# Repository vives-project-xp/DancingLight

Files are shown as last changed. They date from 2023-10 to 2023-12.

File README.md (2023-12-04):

# Dancing Light

## Content

- [Project explained](#project-explained)
- [Effects](#effects)
- [Hardware](#hardware)
- [Software](#software) 
- [Who does/did what?](#who-doesdid-what)
- [Planning](#planning)
- [Future changes](#future-changes)
- [BOM](#bom)
- [Links](#links)
- [License and author info](#license-and-author-info)

## Project explained

The Dancing Light project will make LED's react to music.

We will be working with a sound sensor which will send a signal depending on the strength of the sound/music. Using a Raspberry Pi 4 we can code a program to make this happen. We used VNC for most of our programming (more info in software).

The project will have a few modes. Some generic effects will be added into a program. Lastly the mode which listens to audio input will also be implemented into the project. We use a USB mic to listen to the audio due to the Raspberry Pi only being able to take in digital input on the GPIO pins.

With this mic we can connect it to a USB port on the Pi and make a program which can observe analog input. This way we can visualize sound strength, frequencies and other sound related variables. With the digital pin reading (old mic) way we can only display light for the on and off state.

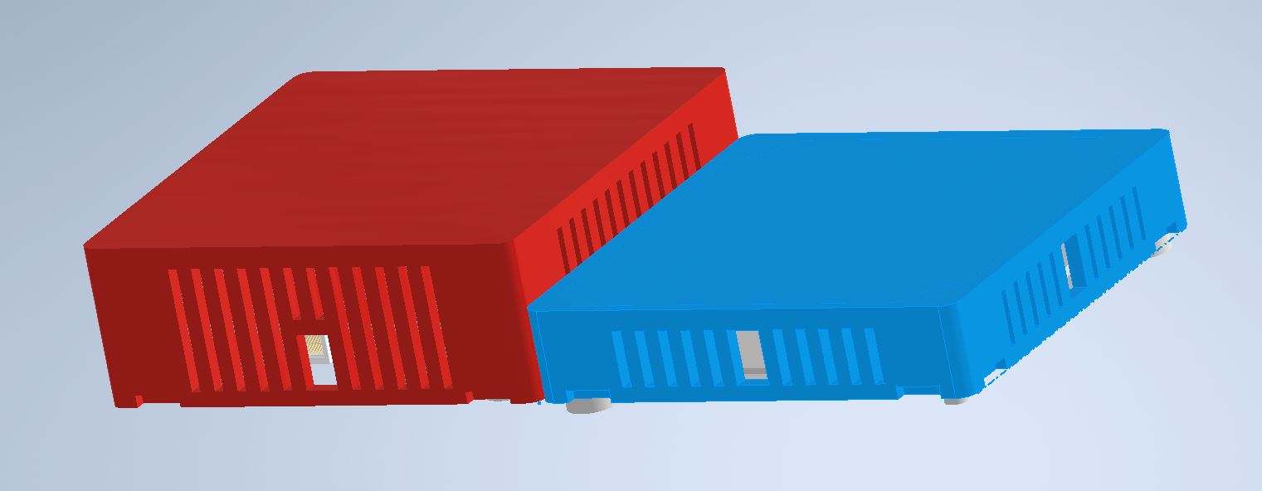
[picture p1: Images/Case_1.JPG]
Case

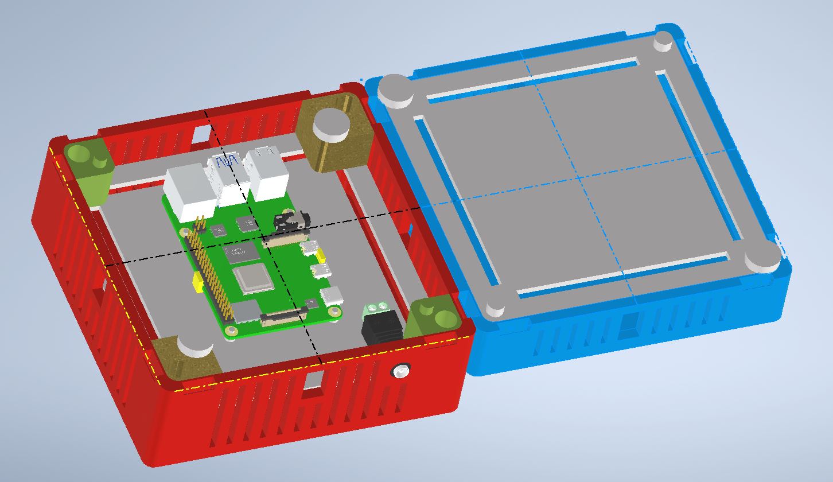
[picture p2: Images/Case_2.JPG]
Case


Taking the entire casing into account it exists out of four different parts. The lid has some holes for air circulation and the top is printed very thin, just so the light of the LEDs is visible from the outside.

At the sides a system was added to connect two cases with each other. It uses an external part to connect the sides. To ensure the same lighting in each box, we decided to add the Pi to the back of the main box. This will make it so the main box will be coming forward when compared to the other boxes when connected to for example a wall. For this proof of concept project we will make three boxes (one with raspberry and two without).

Originally we used two parts which would bridge over the Pi to provide light all over the box, but this caused the issue that you could visually see the LED's on one side and only the light on the other side.

## Effects
These are the effects supported with the MQTT broker
<ul>
    <li>"MiddenBounce"</li>
    <li>"uitbreidReactie"</li>
    <li>"vlakMuziek"</li>
    <li>"ledsMeDb"</li>
    <li>"ledsMeDbFlikker"</li>
    <li>"rainbow"</li>
    <li>"rgbKleur" (rgb effect)</li>
    <li>"ledsMeDbRGB" (rgb effect)</li>
</ul>

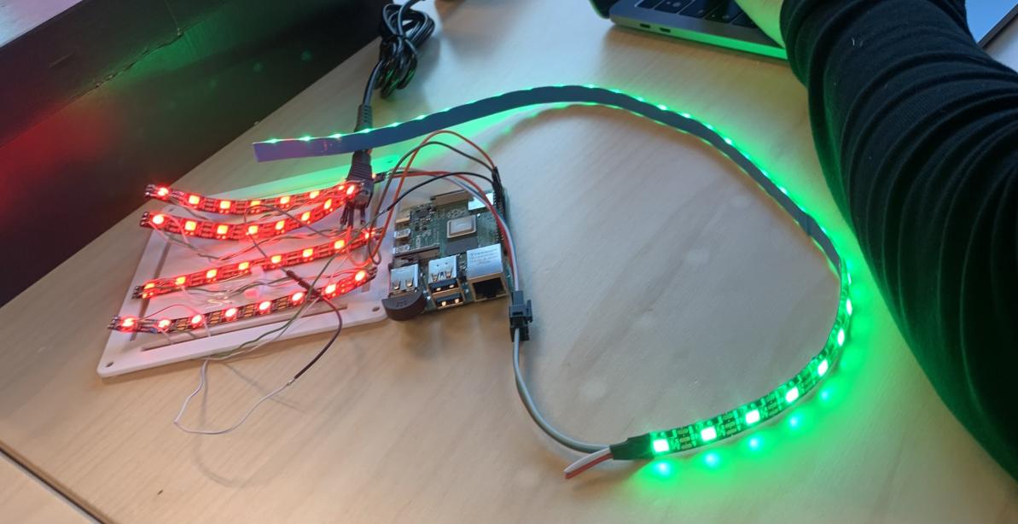
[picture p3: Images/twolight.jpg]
2lights


## Hardware

Our project requires the following hardware and materials to be constructed (links and pricing included in BOM list):

### 1. Raspberry Pi 4

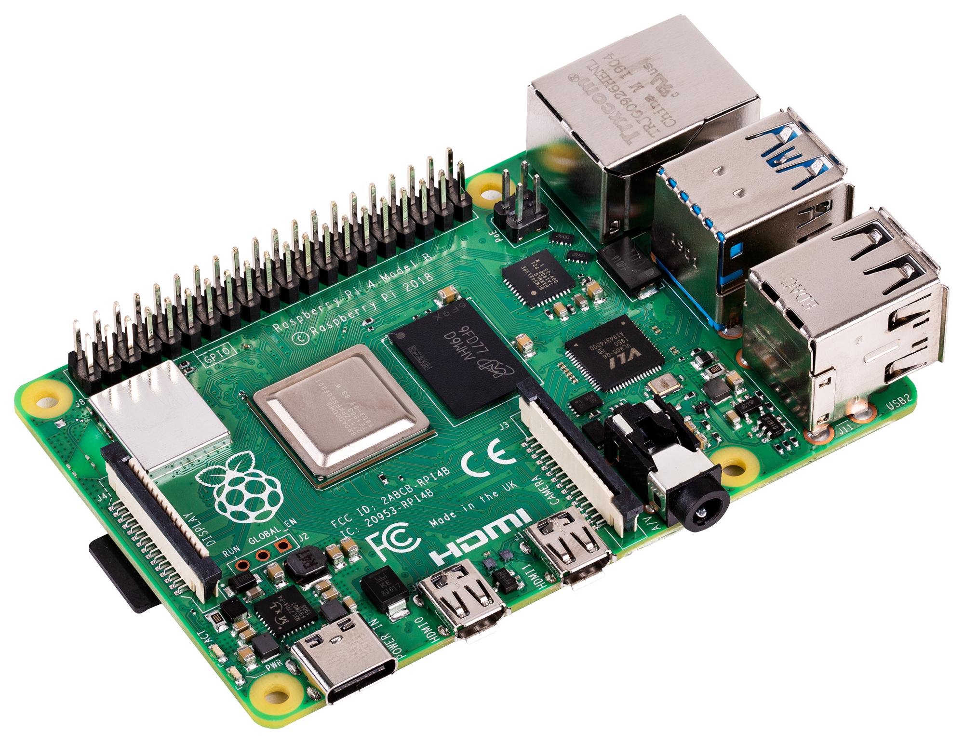
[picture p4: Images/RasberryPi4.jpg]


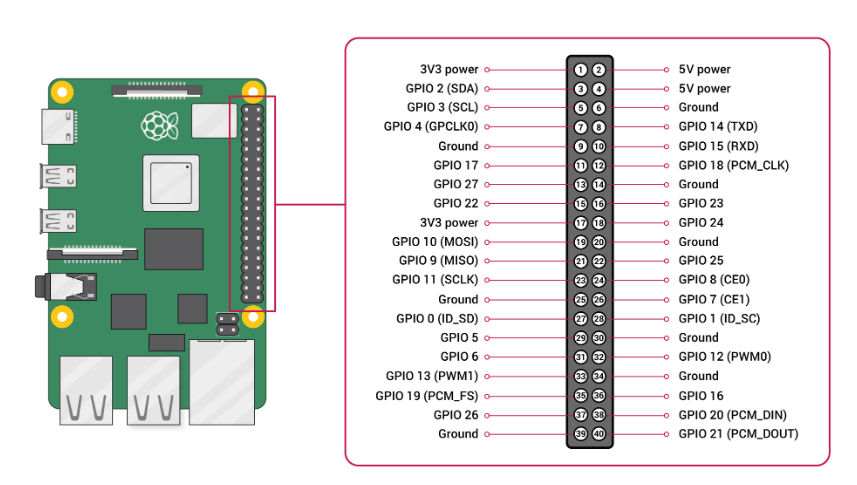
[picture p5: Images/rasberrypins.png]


We use a Raspberry Pi 4 to power and drive our project, this is a powerful way in which we can include many different effects.

### 2. Plug adapter 5V 10A

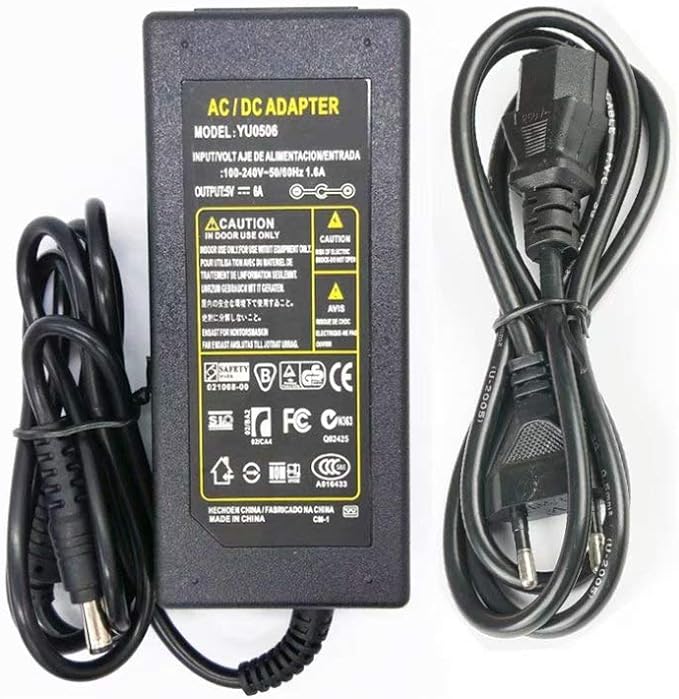
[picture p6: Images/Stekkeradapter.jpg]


Of course the Raspberry Pi 4 needs power to work, for that we use this adapter.

### 3. Adapter -> DC

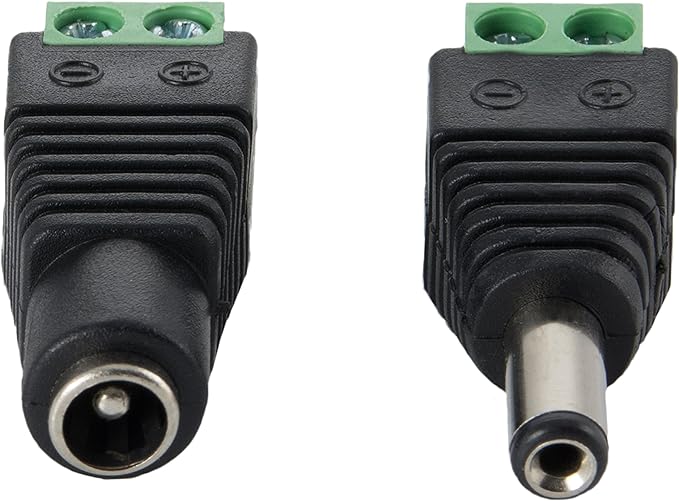
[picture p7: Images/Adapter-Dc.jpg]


### 4. 3 Pin Connector

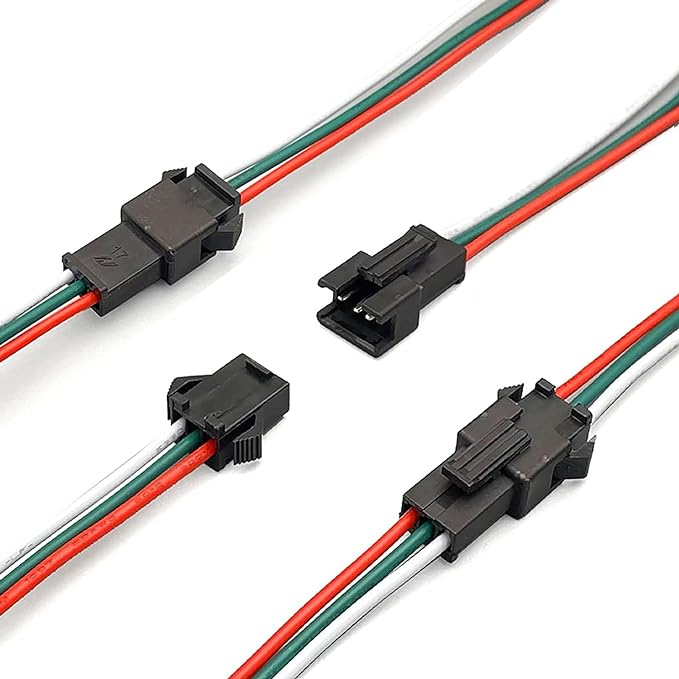
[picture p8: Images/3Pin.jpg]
3Pin


To connect LED strips we use these connectors, which can easily connect LED strips to eachother by just plugging one end into another. 

### 5. LED strip 5V

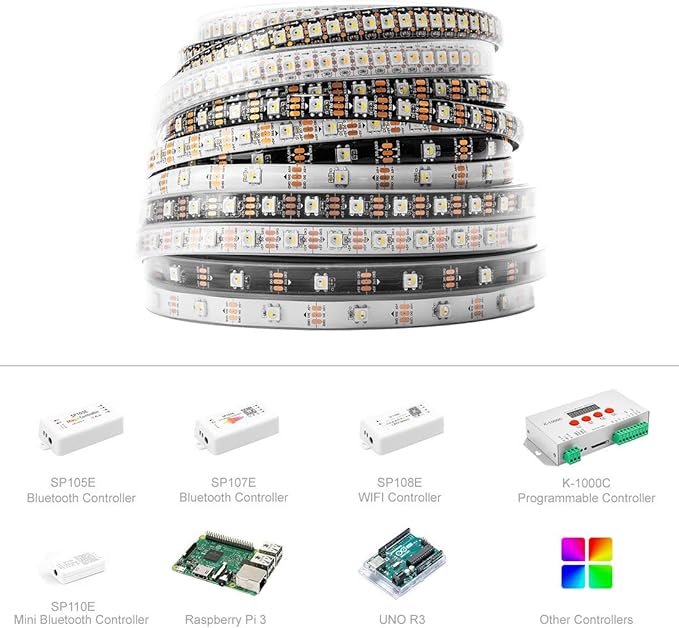
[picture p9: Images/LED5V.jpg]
LEDS


### 6. Sound sensor

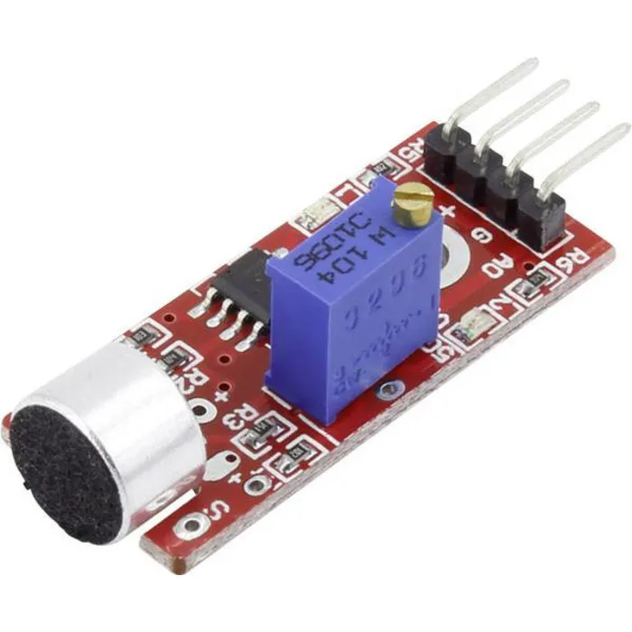
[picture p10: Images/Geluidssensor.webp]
Geluidssensor


Dropped due to low sensitivity, could also only be connected to digital GPIO pins. This way we had to work with a specific value to work around and can also only play an effect when this value is exceeded.

### 7. USB microphone

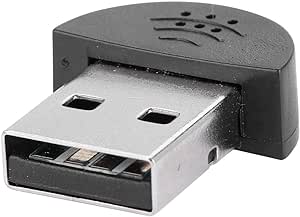
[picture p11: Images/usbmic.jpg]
usb


We chose to use a different approach by using this USB-mic to be able to take in analog input to create effects based on the strength of the sound. With some calculations found online we can determine the decibel rate of the sound. This mic is way more sensitive to sound, even lighting up from silent sounds far away (depending on the chosen value of course).

### 8. Casing 3D prints

## Software

### 1. [VNC Viewer](https://www.realvnc.com/en/connect/download/viewer/):

This is the software we used to program the Raspberry Pi 4. It's easy to set up after installing. An advantage of this software is the ability to work on the same project at the same time. Whenever one person changes something all other members see the changes on their own device live.

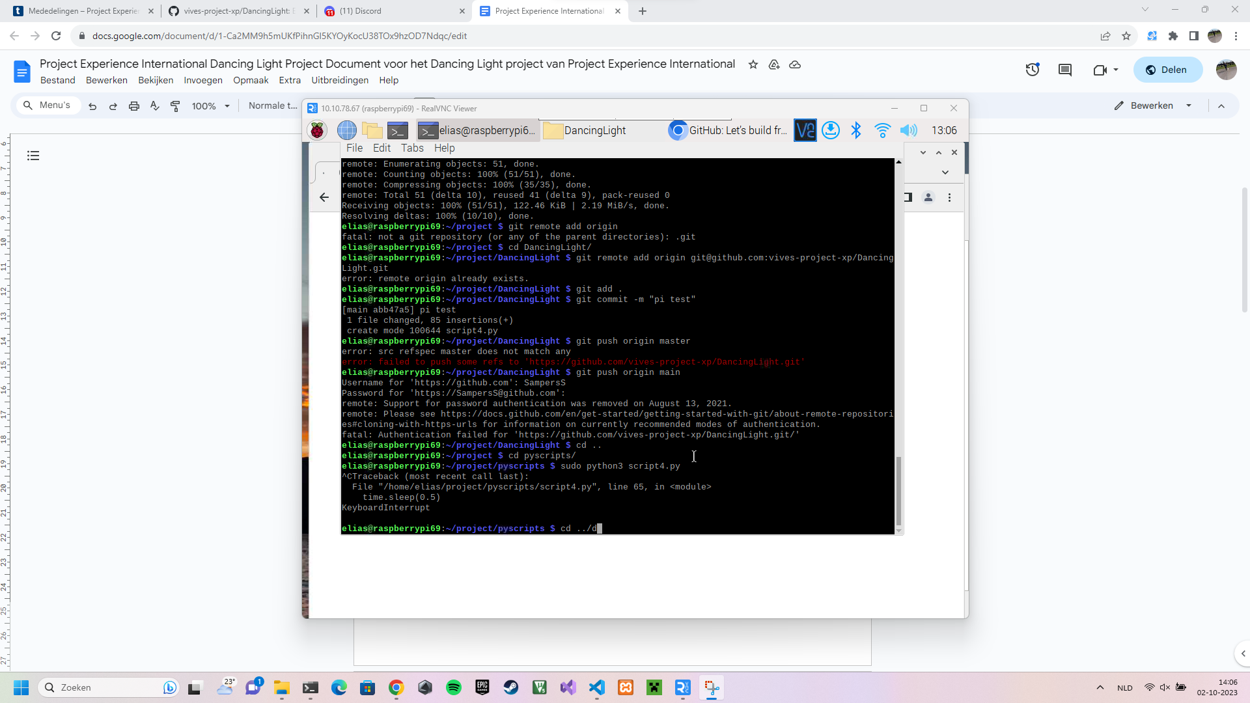
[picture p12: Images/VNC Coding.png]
vnc


&nbsp;

### 2. Python coding environment

VNC viewer has the ability to write code in the program itself, opening the right type of file in your folder.

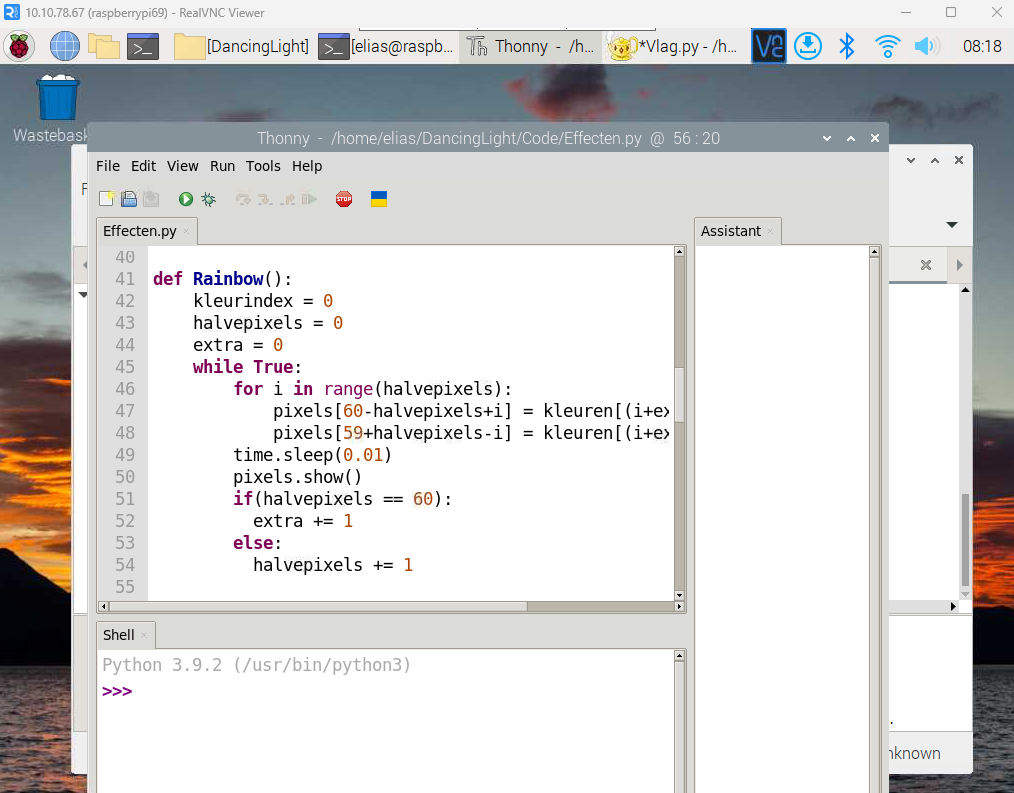
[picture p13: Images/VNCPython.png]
vncpy


### 3. MQTT with [Project Master](https://github.com/vives-project-xp/ProjectMaster)

MQTT gives us the ability to connect with the Project Master. Which makes it possible to send the effects from a central device to the different projects.

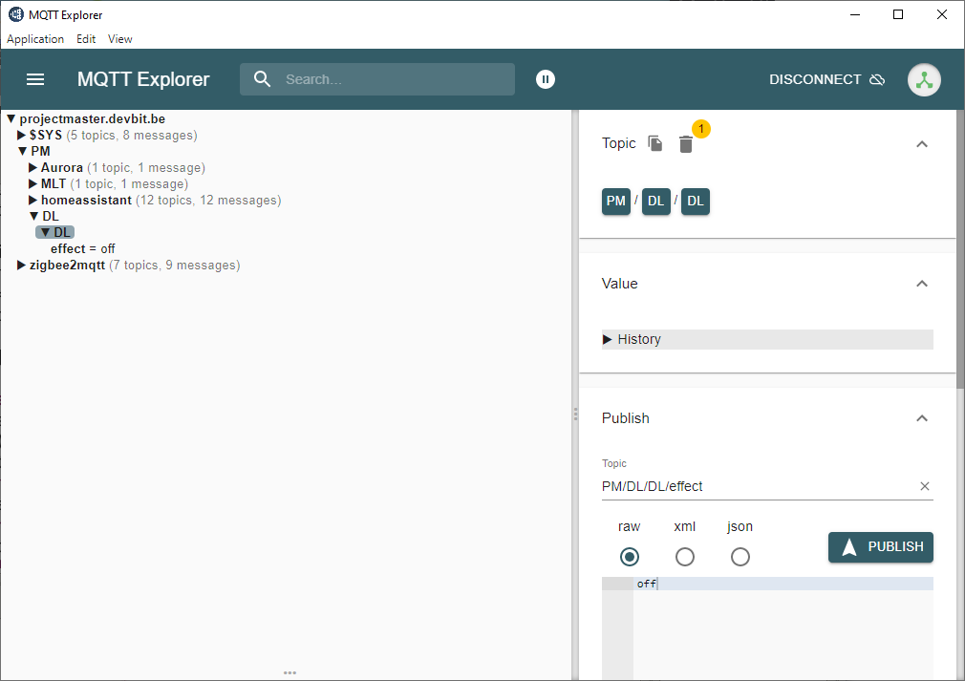
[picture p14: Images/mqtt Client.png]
mqtt


### 4. [Autodesk Inventor Professional 2021](https://www.autodesk.com/products/inventor/overview?term=1-YEAR&tab=subscription)

Inventor gives the ability to make 3D designs for making this project possible. This program also makes it easy to convert the 3D designs to STL files for 3D printing.

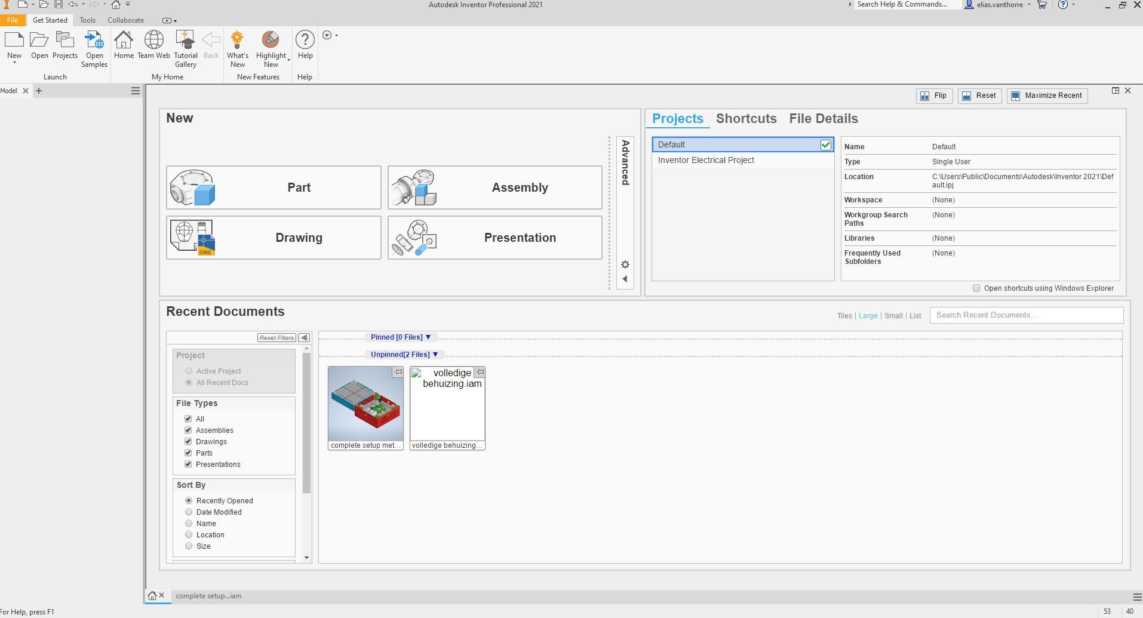
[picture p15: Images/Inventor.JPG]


## How is the box build?
WARNING: When picking the project up from the amgnet board you need to be carefull to not pull it off to quick. And brake the project also the boxes are connect with clips so be carefull when pulling the different boxes apart. 

To disasemble the setup you first need to pull the boxes apart and pull out the clips inbetween of the two boxes.
Secondly you screw off the magnets who are inserted in to the standoffs on both boxes. When the magnets are of you will be able to pull of the lid from the smaller box and you will see the leds. For the bigger boxs you will need to first screw off the spacers out of the biggerbox. These screws are pretty thight so be carefull when unscrewing them. When alle the spacer are unscrewed you will be able to pull of the lid from the bigger box with the pi and wires still attage. For the ease of use you can disconnect the wires going to the pi to get a look in the bigger box. Everything is power by the famel plug and this one is glued in place so be carefull when pulling out the lid. 

## Who does/did what?

- ### Global (entire group)

1. Project defining (What's expected from the project)
2. Project design (Brainstorming about options, designing connection system for multiple products)
3. Material list (Searching cheapest solutions while maintaining quality)
4. Github issues
5. Group meetings

- ### Mirko (Software & ai + Scrum master)

1. Software testing (Making a LED strip function like we want with the Raspberry Pi 4)
2. Searching code
3. Issue management
4. MQTT
5. Coding effects

- ### Seraphin (Software & ai)

1. Software testing (Making a LED strip function like we want with the Raspberry Pi 4)
2. Searching code
3. Rasberry configuration
4. MQTT
5. Coding effects
6. Sound detection on raspberry pi 4

- ### William (Software & ai)

1. Poster design
2. Presentation
3. Searching code for the microphones
4. Integrating hardware to the Raspberry Pi.

- ### Elias (Networks)

1. Looking for power supply solution
2. Case design
3. Rasberry configuration
4. Soldering
5. Assembly
6. README documentation
7. README 3D

- ### Esteban (Software & ai)

1. README documentation
2. Searching code
3. Coding to read mp3 file (and sound visualisation script)
4. Sound coding
5. Coding effects

- ### Planning

1. Testing product (week 7-10)/
    - Software and hardware
    - Casing (does the connection between two products work?)
        1. Top of first case was printed to thick (no light could pass)
        2. Do we use plastic or do we 3D print see trough layer.
2. Optimizing product:
    - Thinner top layer
    - Raspberry Pi added to the back of the case
3. Coding:
    - LED's on sound strength
    - Template lighting for LED's (Done)
4. Case connection (important)
5. MQTT connection (Project master)
6. Document finalization:
    - README
    - Powerpoint final presentation
    - Manage files on Pi
7. Preparing final presentation

## Future changes

1. Adding better solution for connecting the different boxes.
2. More effects

## BOM

| Description | Quantity | Price |
|---|---|---|
| Geluidssensor | 1 | [€0.99](https://www.otronic.nl/nl/geluidssensor-module-voor-arduino.html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) |
|SK6812 5V LED | 2m | [€23](https://www.amazon.nl/BTF-LIGHTING-Vergelijkbare-Individueel-Adresseerbare-Niet-Waterdicht/dp/B01N2PC9KK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) |
| Stekkeradapter 5V 10A 50W| 1 | [€21.99](https://www.amazon.nl/Transformatoren-AC100-240V-Omvormer-Stekkeradapter-Verlichting/dp/B07PBNCFDG?th=1) |
| Adapter omvormer | 1 | [€9.02](https://www.amazon.nl/Poppstar-Adapter-5x2-Connectors-CCTV-camera/dp/B084RHH8LC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) |
| 3Pin Connector | 1 | [€9.99](https://www.amazon.nl/HUAZIZ-vrouwelijk-mannelijke-vrouwelijke-elektrische/dp/B0BPP87N9G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) |
|Raspberry Pi |1|[€86.17](https://www.amazon.nl/Raspberry-Pi-ARM-Cortex-A72-Bluetooth-Micro-HDMI/dp/B07TC2BK1X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)|
|USB Microfoon|1|[€7.11](https://www.amazon.nl/Audio-opnemen-USB-microfoon-omnidirectioneel-Skype-chatten/dp/B08BFHSLGV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)|
| 3D printing | 1 | €4 (reserved) |

Total: €158.27 (3D printing excluded)

## Links

Github: https://github.com/vives-project-xp/DancingLight
Installatie instructies: https://github.com/vives-project-xp/DancingLight/blob/main/INSTALLATION.md

## License and author info

Made by Mirko Sinnaeve, Seraphin Sampers, William Rogov, Elias Vanthorre en Esteban Desmedt in 2023-2024, semester 1 for VIVES.

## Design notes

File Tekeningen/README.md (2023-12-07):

# 3D models

All parts are made in the software Inventor Professional 2021. To open the project the best thing to do is to open the assembly, "complete setup met relief", in the "13_11_2023" folder.

This way you open all the parts that are needed for this project and you can see how all the parts fit together. In the pictures below you will see the assembly with a numbering of what the parts are/what they do with the naming of this part. All the parts are 3D printed except the stand-offs and bought parts like the Raspberry Pi and barrel jack.

The folder with name "13_11_2023" is where all the latest pieces are. The other folder with name "13_11_2023 stukken niet meer nodig", are pieces who where made in the prototyping stage and are not needed anymore for the project.

If you want to remake this project on your own 3D printer that is possible with the 3D stl files provided in the map "STL 14-11-2023" and "STL 27-11-2023".

## Description of the parts

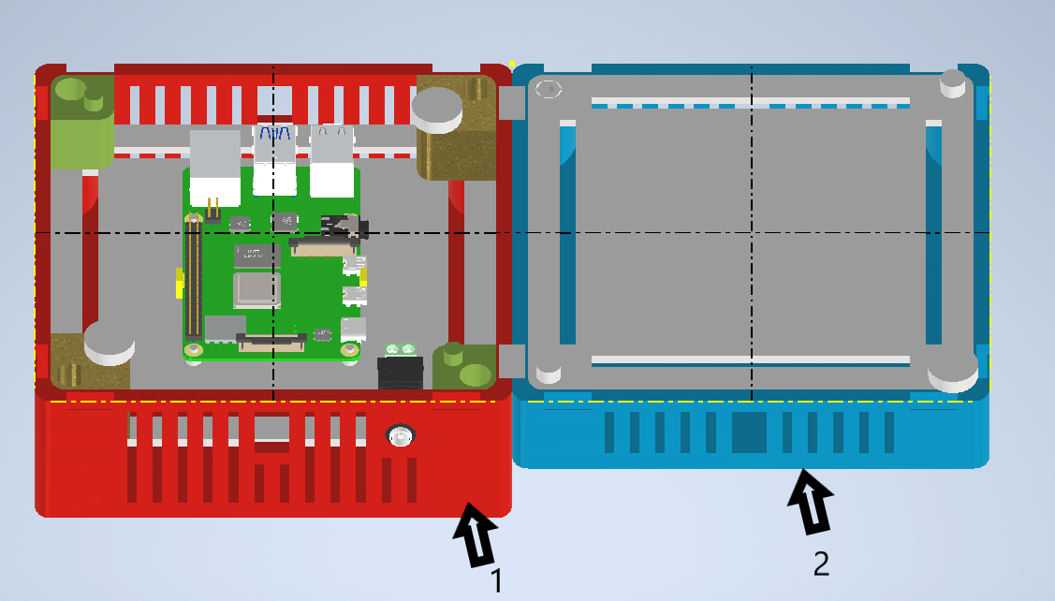
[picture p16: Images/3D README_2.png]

The name of each part in the 13_11_2023 folder is in brackets.

1. The highest case (Led behuizing dubbele hoogte).

2. The lower form of the case (Led behuizing).

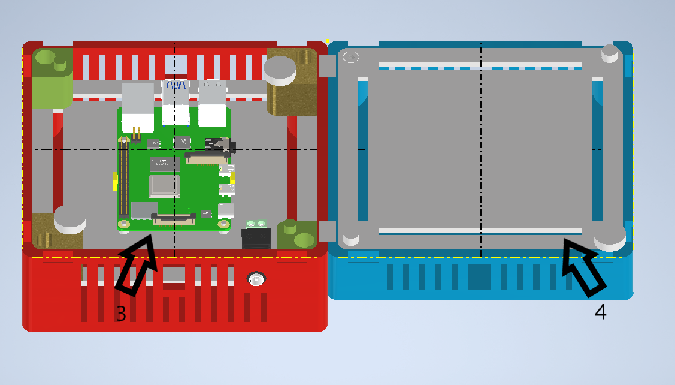
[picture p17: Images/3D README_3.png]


3. The lid where the Pi is mounted on (Led deksel hub).

4. The lid without a Pi (Led deksel hub zonder pi).

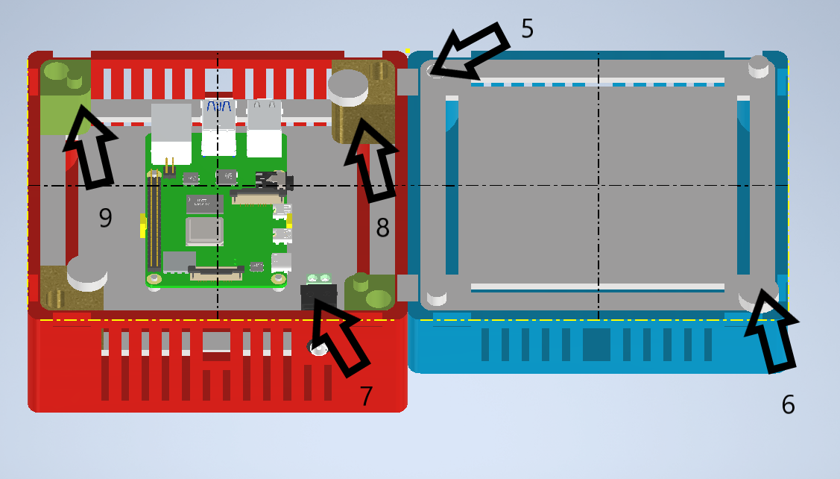
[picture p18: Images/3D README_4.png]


5. Magnet stand-offs small box (magneet stand-offs).

6. Magnet (magneet).

7. This is the power barrel jack this is an assembly in an assembly (dc-barrel-jack-adapter-female).

8. Spacer to make it possible to use the magnets (spacer dubbele hoogte behuizing).

9. Spacer without the magnets for the big box (spacer dubbele hoogte behuizing zonder magneet).

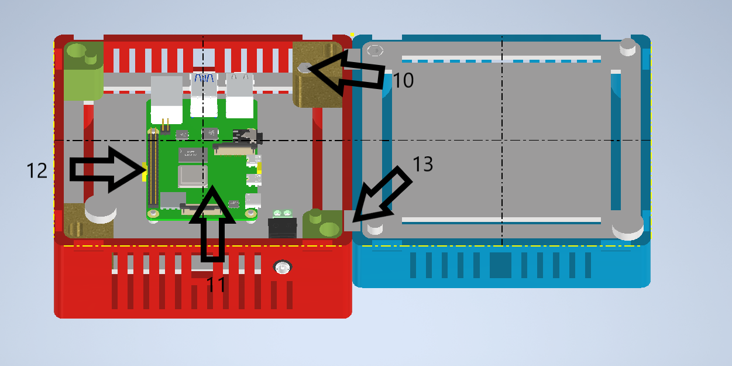
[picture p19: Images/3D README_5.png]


10. This is the spacer for the higher box (mangeet stand-offs16 mm).

11. This is the raspberry pi (Raspberry Pi 4 Model B).

12. The Pi holder that is glued on the lid (houderpi).

13. This is the merge piece that keeps the two boxes together (koppelstuk).

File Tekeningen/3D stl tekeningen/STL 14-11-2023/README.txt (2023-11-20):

Zowel de stl als de .gcode files heb ik hier geplaats. 
De .gcode files heb ik zelf gesliced via de crealty print slicer op basis van de ender-3 S1 PLUS. Maar met dezelfde settings waarmij ik op mijn eigen ender 3 pro de behuizing reeds geprint heb (succesvol).
Het gebruiken van deze .gcode is geen garantie op succes op de S1 PLUS maar het werd gevraagd dat ik deze reeds slice via mijn settigns vandaar.
De vorige print die ontvangen werd via het school had enige defecten zoals het warpen van de grote onderdelen als ook het niet mooi afwerken van openvlaktes. 
Wat me ook opviel bij de prints is dat deze op elk aspect toch enkele mms te groot uitvielen heb geen idee wat hiervan de reden zou kunnen zijn. (bij het printen thuis had ik hiermee niet direct een probleem)
in de images case_1 en case_2 krijg je een overzicht van hoe het geheel er zou moeten uitzien.

Naam stl						kleur			printer			aantal		opmerking

Houderpi 						gelijk 			gelijk			1		bij het gebruiken van de stl gelieve te zorgen dat de ribbel loodrecht light t.o.v. de build plate

Led behuizing dubbele hoogte				Wit			ender-3 S1 PLUS		1

Led behuizing						Wit			ender-3 S1 PLUS		1

Led deksel hub zonder pi				wit			ender-3 S1 PLUS		1

Led deksel hub						wit			ender-3 S1 PLUS		1

spacer dubbele hoogte behuizing zonder magneet		gelijk			gelijk			2

spacer dubbele hoogte behuizing				gelijk			gelijk			2

Als de keuze wordt gemaakt om mijn .gcode te gebruiken hier wat nuttige info (het kan zijn dat er wat stringing aanwezig is)

Naam .gcode								print tijd		support		infill

Ender-3 S1 Plus_Houderpi						15min			geen		50%
			
Ender-3 S1 Plus_Led behuizing dubbele hoogte				36h			ja		50%

Ender-3 S1 Plus_Led behuizing						22h			ja		50%

Ender-3 S1 Plus_Led deksel hub zonder pi				6h			geen 		50%

Ender-3 S1 Plus_Led deksel hub						6,15h			geen		50%

Ender-3 S1 Plus_spacer dubbele hoogte behuizing zonder magneet		1,1h			geen		50%

Ender-3 S1 Plus_spacer dubbele hoogte behuizing				1,3h			geen		50%

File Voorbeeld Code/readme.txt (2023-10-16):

in deze map zit code van het internet die de nodige stappen en ideën bevat om dingen te doen. Het is niet de bedoeling dat je deze code aanpast, je gebruikt dit enkel voor het copiëeren naar je eigen code. peace.

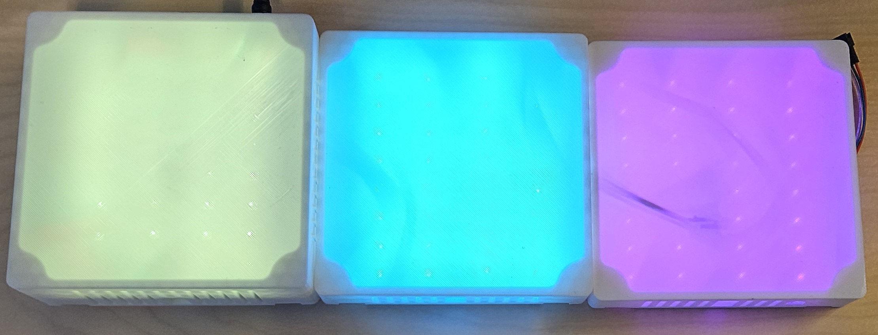
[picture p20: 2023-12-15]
Images/Presentatie/foto_2.jpg

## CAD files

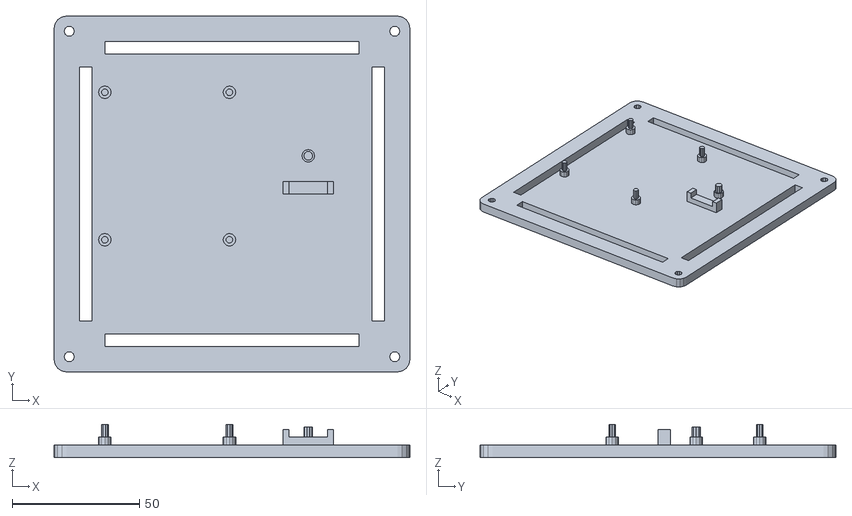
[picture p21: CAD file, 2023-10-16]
Tekeningen/3D stl tekeningen/STL 16-10-2023 niet meer nodig/Led deksel main unit.stl
140.0 x 140.0 x 13.0

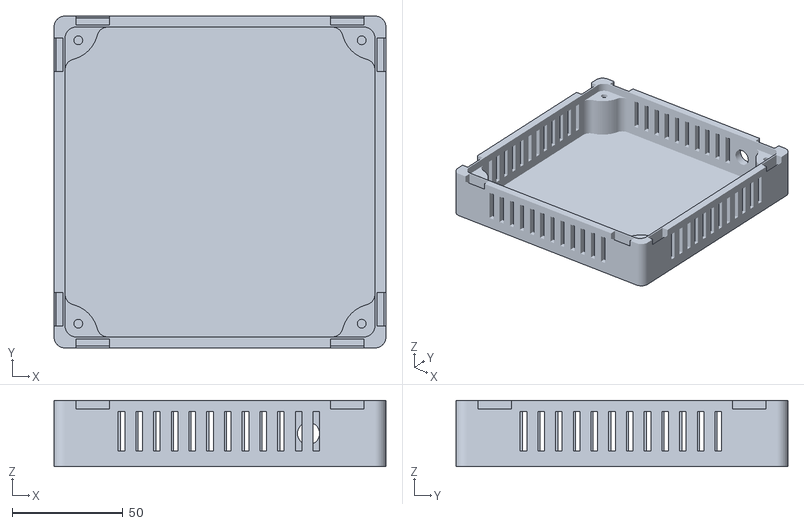
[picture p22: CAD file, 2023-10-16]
Tekeningen/3D stl tekeningen/STL 16-10-2023 niet meer nodig/Led behuizing main unit.stl
150.0 x 150.0 x 30.0

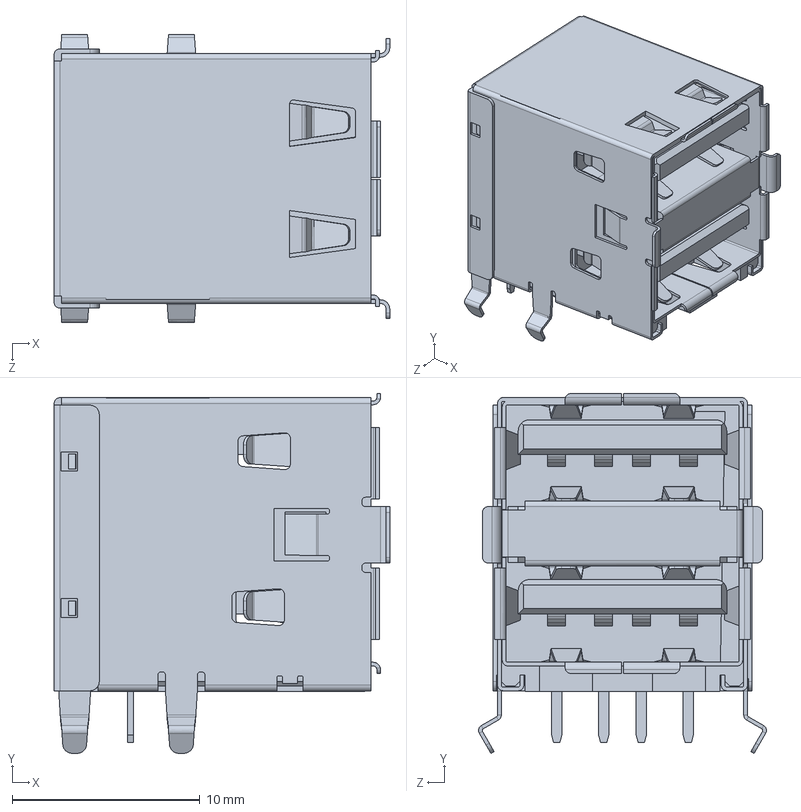
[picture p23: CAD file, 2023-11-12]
Tekeningen/13_11_2023 stukken niet meer nodig/raspberrypi/2X USB2.0 PORTS, RPi4ModelB.SLDPRT
17.9 x 19.2 x 15.3 mm

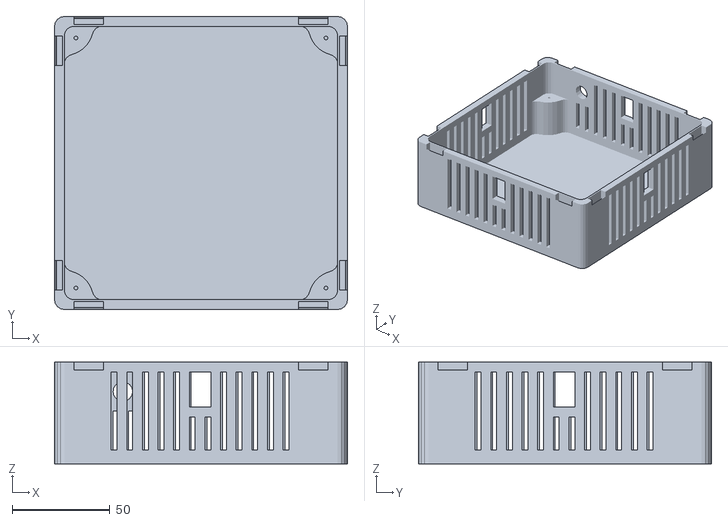
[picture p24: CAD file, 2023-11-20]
Tekeningen/3D stl tekeningen/STL 14-11-2023/Led behuizing dubbele hoogte.stl
150.0 x 150.0 x 52.0

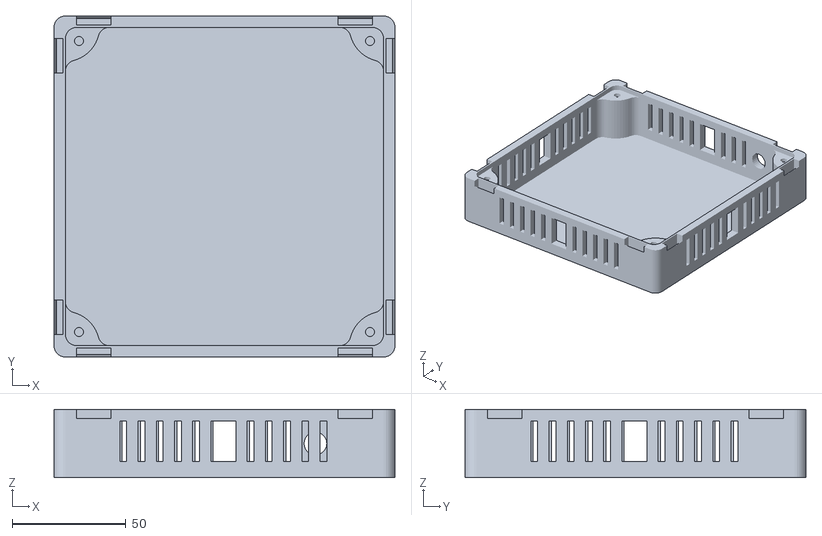
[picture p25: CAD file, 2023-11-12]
Tekeningen/3D stl tekeningen/STL 16-10-2023 niet meer nodig/Led behuizing.stl
150.0 x 150.0 x 30.0

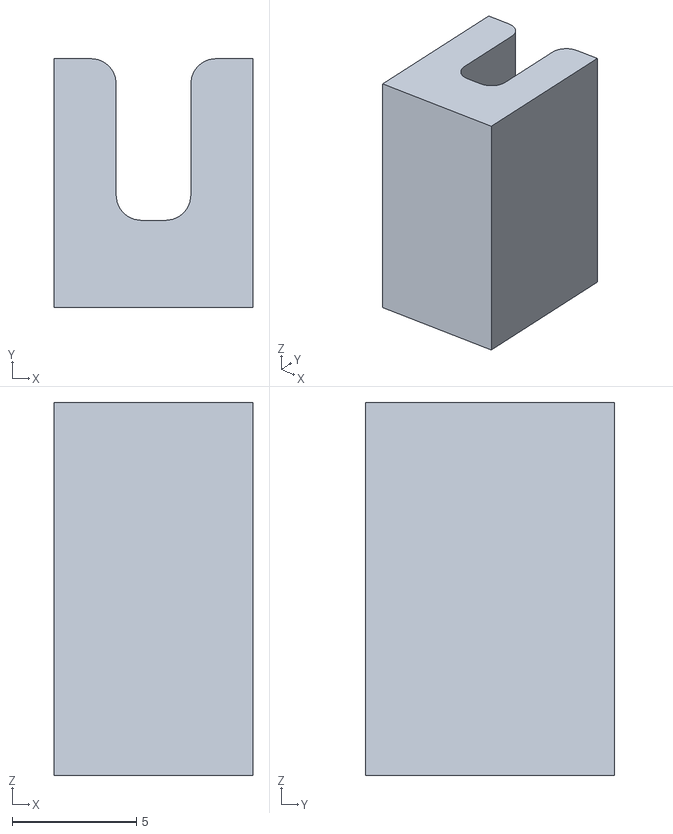
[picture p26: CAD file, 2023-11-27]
Tekeningen/3D stl tekeningen/STL 27-11-2023/koppelstuk_2.stl
8.00 x 10.0 x 15.0

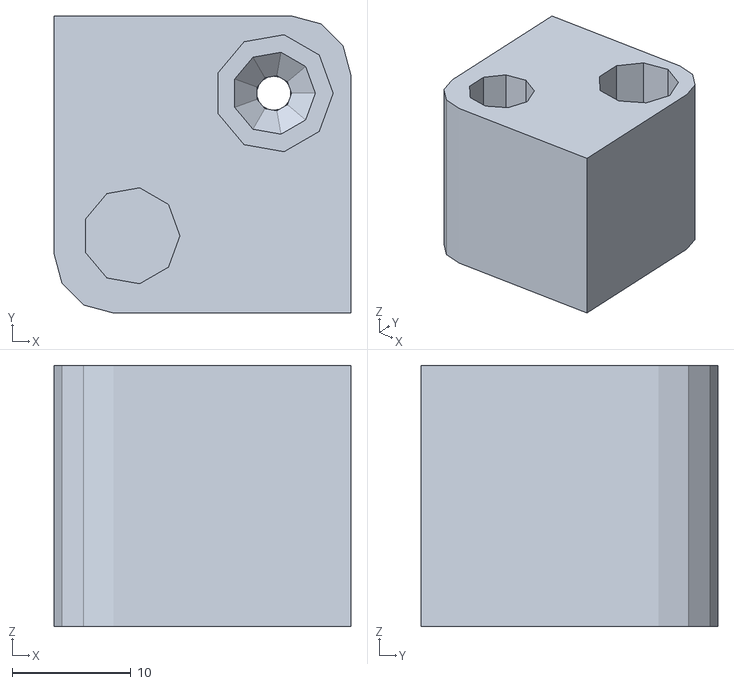
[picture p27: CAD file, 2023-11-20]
Tekeningen/3D stl tekeningen/STL 14-11-2023/spacer dubbele hoogte behuizing.stl
25.0 x 25.0 x 22.0

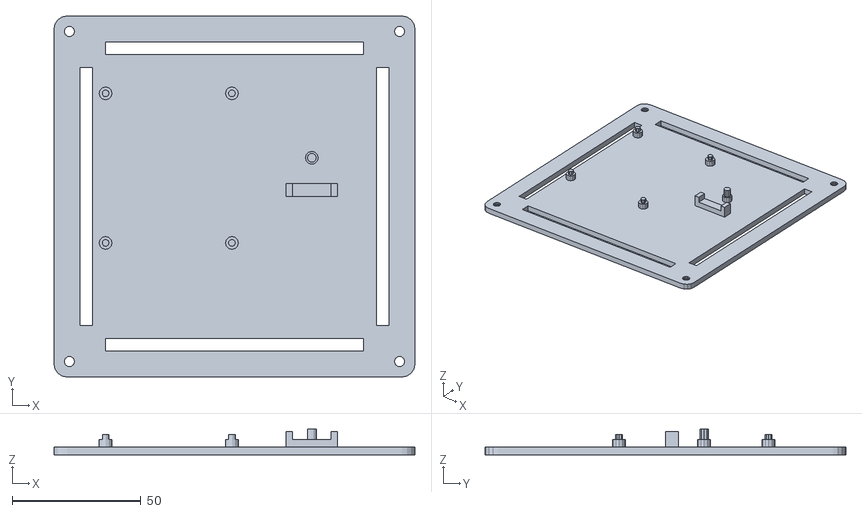
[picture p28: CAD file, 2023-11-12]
Tekeningen/3D stl tekeningen/STL 16-10-2023 niet meer nodig/Led deksel.stl
140.0 x 140.0 x 10.0

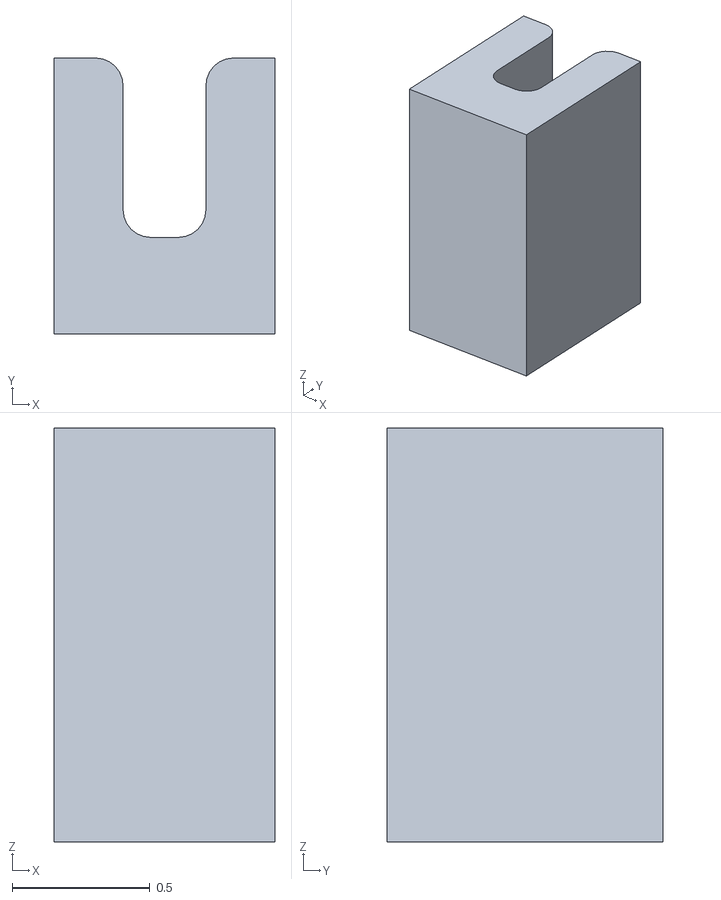
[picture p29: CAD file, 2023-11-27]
Tekeningen/3D stl tekeningen/STL 27-11-2023/koppelstuk.stl
0.8 x 1.00 x 1.50

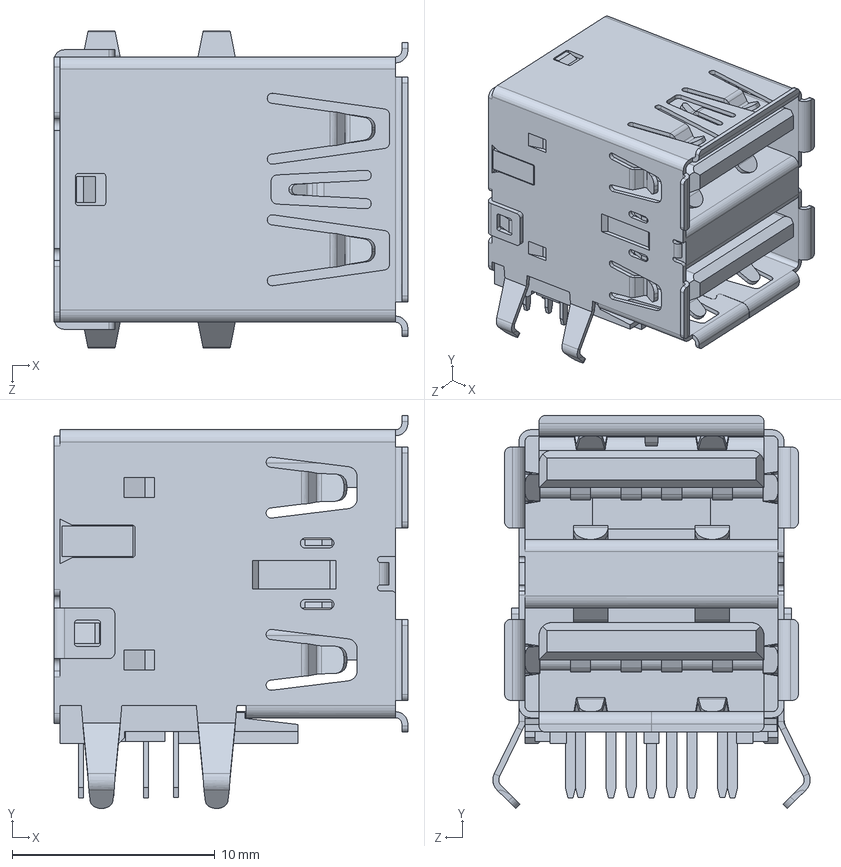
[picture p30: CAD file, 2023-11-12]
Tekeningen/13_11_2023 stukken niet meer nodig/raspberrypi/2X USB3.0 PORTS, RPi4ModelB.SLDPRT
17.5 x 19.4 x 15.7 mm

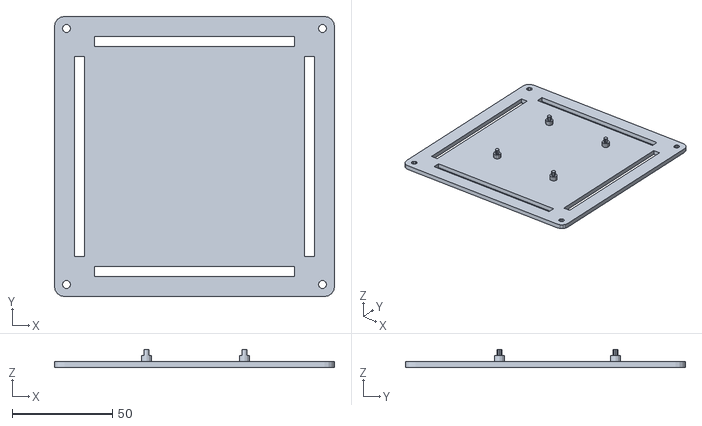
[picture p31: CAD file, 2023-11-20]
Tekeningen/3D stl tekeningen/STL 14-11-2023/Led deksel hub.stl
140.0 x 140.0 x 9.00

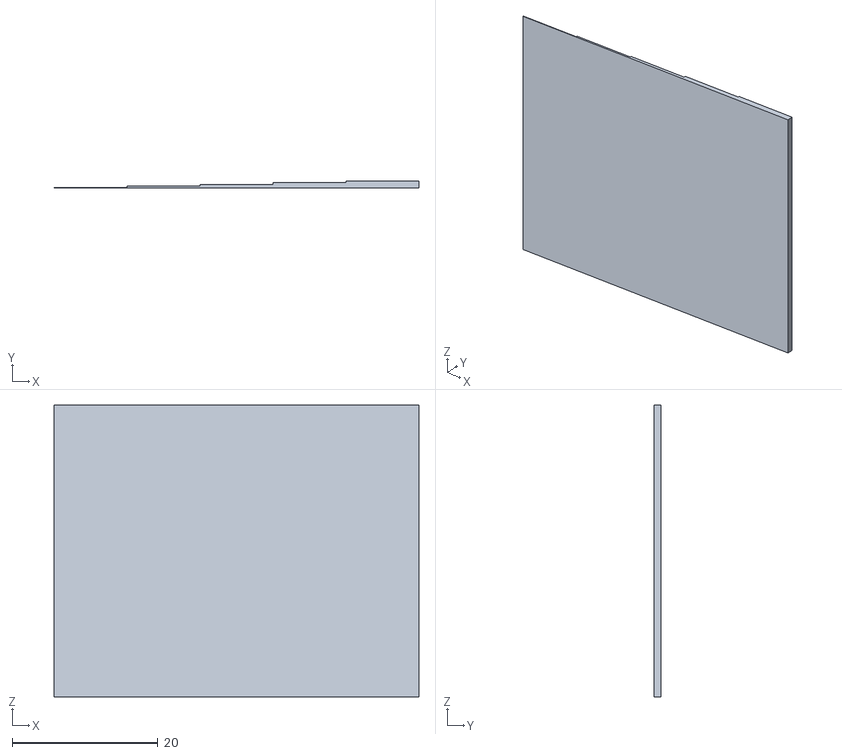
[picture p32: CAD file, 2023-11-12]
Tekeningen/3D stl tekeningen/STL 16-10-2023 niet meer nodig/trap voor licht.stl
50.0 x 1.00 x 40.0

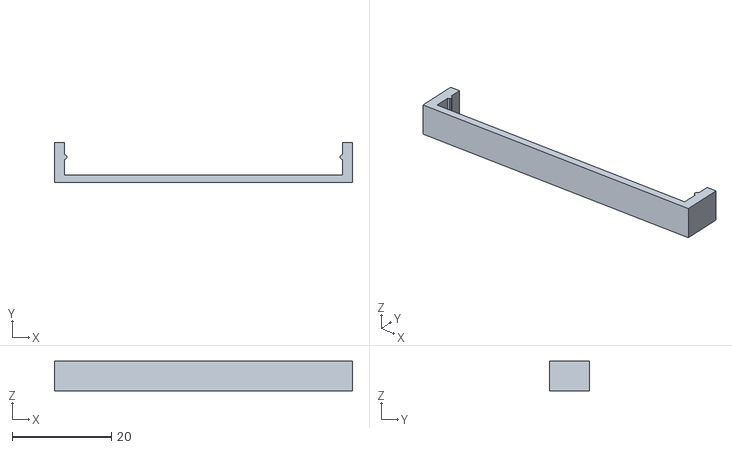
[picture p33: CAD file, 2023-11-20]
Tekeningen/3D stl tekeningen/STL 14-11-2023/Houderpi.stl
60.0 x 8.00 x 6.00

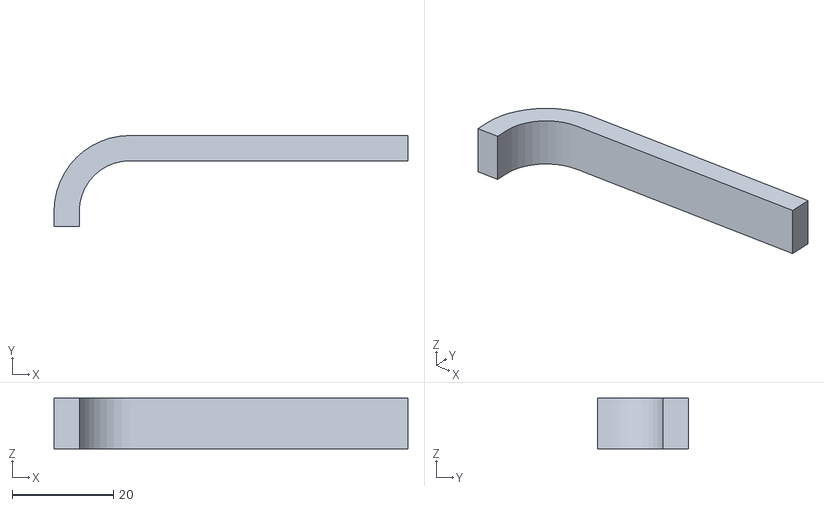
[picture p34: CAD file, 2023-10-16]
Tekeningen/3D stl tekeningen/STL 16-10-2023 niet meer nodig/zweef stuk voor pi.stl
70.0 x 18.0 x 10.0

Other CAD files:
Tekeningen/13_11_2023 stukken niet meer nodig/raspberrypi/Microphone Plug, RPi4ModelB.SLDPRT
Tekeningen/3D stl tekeningen/STL 14-11-2023/spacer dubbele hoogte behuizing zonder magneet.stl
Tekeningen/13_11_2023 stukken niet meer nodig/Led Behuizing_V_2.ipt
Tekeningen/13_11_2023 stukken niet meer nodig/Led behuizing dubbele hoogte.ipt
Tekeningen/13_11_2023 stukken niet meer nodig/Led behuizing.ipt
Tekeningen/13_11_2023 stukken niet meer nodig/Led deksel niet hub.ipt
Tekeningen/13_11_2023 stukken niet meer nodig/Led deksel.ipt
Tekeningen/13_11_2023 stukken niet meer nodig/Microphone Module.ipt
Tekeningen/13_11_2023 stukken niet meer nodig/Raspberry Pi 4 Model B.iam
Tekeningen/13_11_2023 stukken niet meer nodig/dc-barrel-jack-adapter-female-with-screw-terminals-1.snapshot.2/92000A013.ipt
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

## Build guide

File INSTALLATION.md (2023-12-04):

# Installation Guide

## Table of Contents

- [BOM (Bill of Materials)](#bom-bill-of-materials)
- [Installation](#installation)
  - [Step 1: Install Raspberry Pi OS](#step-1-install-raspberry-pi-os)
  - [Step 2: Enable VNC](#step-2-enable-vnc)
  - [Step 3: Clone the git repository](#step-3-clone-the-git-repository)
  - [Step 4: Install the required packages](#step-4-install-the-required-packages)
  - [Step 5: Run the code](#step-5-run-the-code)
  - [Step 6: Change the Effect with MQTT Explorer](#step-6-change-the-effect-with-mqtt-explorer)
  - [Step 7: Make the program run on boot (optional)](#step-7-make-the-program-run-on-boot-optional)

## BOM (Bill of Materials)

| Description | Quantity | Price |
|---|---|---|
| Geluidssensor | 1 | [€0.99](https://www.otronic.nl/nl/geluidssensor-module-voor-arduino.html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) |
|SK6812 5V LED | 2m | [€23](https://www.amazon.nl/BTF-LIGHTING-Vergelijkbare-Individueel-Adresseerbare-Niet-Waterdicht/dp/B01N2PC9KK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) |
| Stekkeradapter 5V 10A 50W| 1 | [€21.99](https://www.amazon.nl/Transformatoren-AC100-240V-Omvormer-Stekkeradapter-Verlichting/dp/B07PBNCFDG?th=1) |
| Adapter omvormer | 1 | [€9.02](https://www.amazon.nl/Poppstar-Adapter-5x2-Connectors-CCTV-camera/dp/B084RHH8LC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) |
| 3Pin Connector | 1 | [€9.99](https://www.amazon.nl/HUAZIZ-vrouwelijk-mannelijke-vrouwelijke-elektrische/dp/B0BPP87N9G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) |
|Raspberry Pi |1|[€86.17](https://www.amazon.nl/Raspberry-Pi-ARM-Cortex-A72-Bluetooth-Micro-HDMI/dp/B07TC2BK1X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)|
|USB Microfoon|1|[€7.11](https://www.amazon.nl/Audio-opnemen-USB-microfoon-omnidirectioneel-Skype-chatten/dp/B08BFHSLGV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)|
| 3D printing | 1 | €4 (voorbehouden) |

Totaal: €158.27 (exclusief 3D print)

## Installation

### Step 1: Install Raspberry Pi OS

Firstly, you are going to need to install Raspberry Pi OS on your Raspberry Pi.

You can start by downloading the Raspberry Pi Imager from the [Raspberry Pi website](https://www.raspberrypi.org/software/).

Once you have downloaded the Raspberry Pi Imager, you can open it and select the Raspberry Pi OS (32-bit) option.

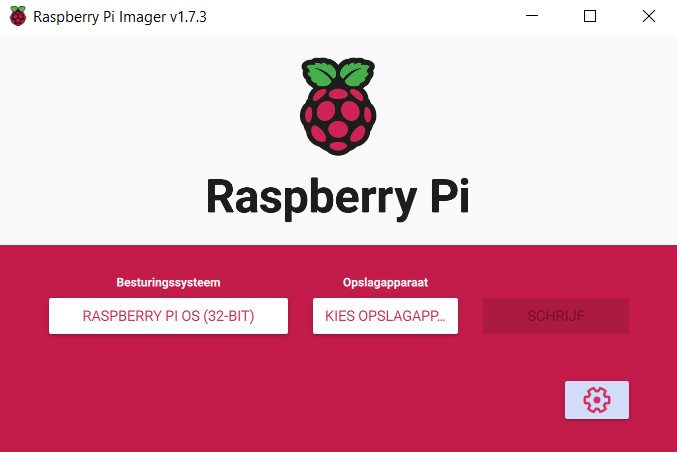
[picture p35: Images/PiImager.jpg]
Raspberry Pi Imager


Next, you will need to select the SD card you want to install Raspberry Pi OS on. Make sure you have selected the correct SD card, as the Raspberry Pi Imager will format the SD card.

### Step 2: Enable VNC

Once you have installed Raspberry Pi OS on your Raspberry Pi, you will need to enable VNC so you can access the Raspberry Pi remotely.

To enable VNC, you will need to open the Raspberry Pi Configuration tool. You can do this by opening the terminal and typing `sudo raspi-config`. Once you have opened the Raspberry Pi Configuration tool, you will need to navigate to the `Interface Options` menu. In this menu, you will need to select the `VNC` option and enable it.

You can also use the graphical desktop to enable VNC. To do this, you will need to open the `Raspberry Pi Configuration` tool from the `Preferences` menu. Once you have opened the `Raspberry Pi Configuration` tool, you will need to navigate to the `Interfaces` tab. In this tab, you will need to select the `VNC` option and enable it.

When you have enabled VNC on the Raspberry Pi, you will need to install the VNC Viewer on your computer. You can download the VNC Viewer from the [RealVNC website](https://www.realvnc.com/en/connect/download/viewer/).

### Step 3: Clone the git repository

To run our code on the Raspberry Pi, you will need to clone our git repository. You can do this by opening the terminal and installing git with the following command:

```bash
sudo apt install git
```

Once you have installed git, you can clone our git repository with the following command:

```bash
git clone https://github.com/vives-project-xp/DancingLight.git
```

### Step 4: Install the required packages

To successfully run our code, you will need to install the required packages. You can do this by opening the terminal and navigating to the `DancingLight` directory. Once you are in the `DancingLight` directory, you can install the required packages with the following commands:

```bash
sudo apt install python3 python3-paho-mqtt python3-pyaudio libportaudio0 libportaudio2 libportaudiocpp0 portaudio19-dev
```
Now install some other packages with the python package manager:
```bash
pip3 install adafruit-circuitpython-neopixel rpi-ws281x
```

### Step 5: Run the code

To run our code, you will need to open the terminal and navigate to the `DancingLight` directory. Once you are in the `DancingLight` directory, you can run the code with the following command:

```bash
python3 main.py
```

### Step 6: Change the Effect with MQTT Explorer

First you need to configure the right credentials and mqtt settings on the pi, for this you need to create a file named "mqttCred.conf" in the root folder. In this file you have to paste the following and change the ### with the mqtt settings you recieve from your mqtt broker admin, if you don't use a local broker but still want to command the boxes you can use an online broker (test.mosquitto.org on port 1883), you can define you own toppics there and have to use an empty string for password an user:
```bash
port:
###
broker_address:
###
user:
###
password:
###
effect-topic:
###
rgb-topic:
###
command-topic:
###
rgb2-topic:
###
```
To change the effect, you will need to install MQTT Explorer on your computer. You can download MQTT Explorer from the [MQTT Explorer website](http://mqtt-explorer.com/).
When opening MQTT Explorer you need to click on the +Connections and enter the same configuration that you entered in the "mqttCred.conf" file.
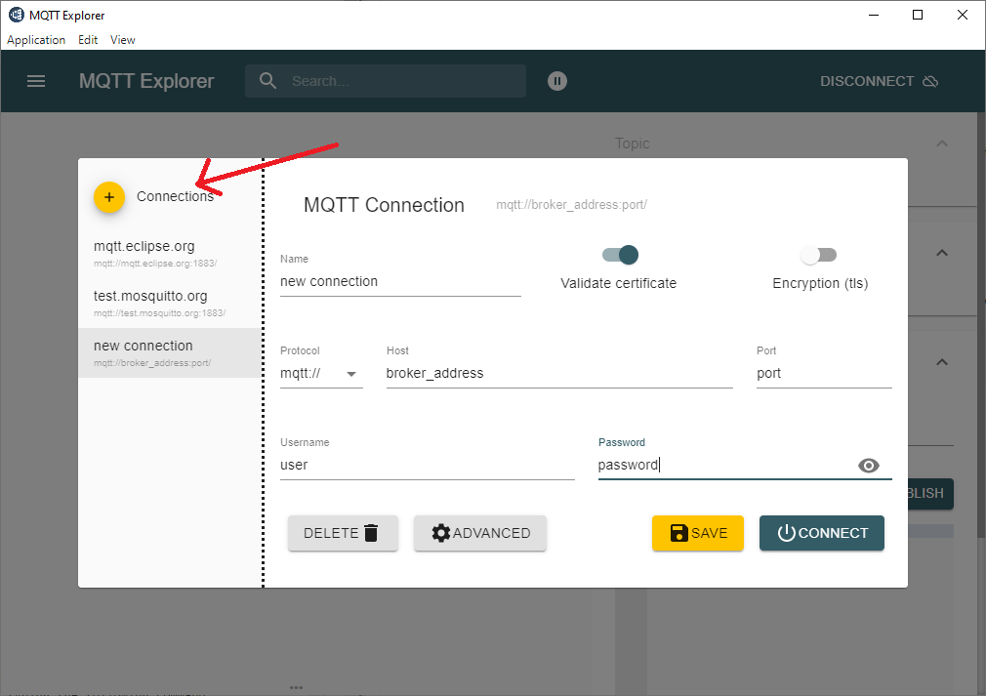
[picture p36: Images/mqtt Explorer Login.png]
Inlog mqtt explorer

then you click connect and you wil get to a screen that looks a bit like this:
MQTT Main
There are a few types of info you can give to the boxes:
<ul>
  <li>Which effect it needs to play</li>
  <li>A command to turn the box off or on</li>
  <li>What rgb value there needs to be for effects that are rgb based</li>
</ul>
To give information to the boxes you need to go to the section "Publish" and then type by "Topic the topic you entered in "mqttCred.conf", select "raw" and type the effect, command or rgb-value that you want, then click on "Publish". A list of all effects you can find in this repo under documentatie/mqtt broker.txt. for rgb value you need to give the decimal values of the RGB values seperated with commas (',') without spaces, Example: "255,0,255".

### Step 7: Make the program run on boot (optional)

To make the project plug and play, you can make the program run on boot. You will first need to change the ALSA Sound Driver a bit. You can do this by opening the terminal and typing the following command:

```bash
sudo nano /etc/asound.conf
```

Then you will need to paste the following code in the file:

```bash

pcm.!default {
  type asym
  capture.pcm "mic"
}
pcm.mic {
  type plug
  slave {
    pcm "hw:1,0"
  }
}
```

Do the same for the file /home/pi/.asoundrc

```bash
sudo nano /home/pi/.asoundrc
```
The last change you need to make is adding this line to:

```bash
/etc/modprobe.d/alsa-base.conf
```

```bash
options snd slots=snd-bcm2835,snd-usb-audio,vc4,vc4
```

To make the program run on boot, you will need to run the script in rc.local

```bash
sudo nano /etc/rc.local
```

Add the following line before the exit 0 line:

```bash
sudo python3 /home/pi/DancingLight/main.py &
```

Add this line before the exit 0 line.

Hopefully, the program will now run on boot and you can enjoy the project!

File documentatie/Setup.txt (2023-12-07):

plaats "mqtt effecten.txt" in de "/" map van de pi

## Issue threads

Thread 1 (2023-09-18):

BOM

mSinnaeve04, 2023-09-18:
**Describe the Issue**
Bill of Materials needs to be made

**Additional context**
Everything we need to order.

Closed 2023-09-25.

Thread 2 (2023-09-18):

Definiëren van led kleuren algoritmes.

SampersS, 2023-09-18:
Dit zal live audio nemen uit de microfoon en terzelfde tijd aanwijzen welke leds met welke kleuren moeten branden.

enkele voorstellen:
kleuren pallet aan de hand van verschill in frequenties
helderheid aan de hand van de beat (bpm)
ook beetje helderheid aan de hand van decibel

Wordt geschreven in python als we een raspberry pi gebruiken en c als we een microcontroller gebruiken.

Closed 2023-10-16.

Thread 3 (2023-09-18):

MQTT broker configureren

SampersS, 2023-09-18:
We configureren een MQTT broker zodat hij werkt.

Dit houd zich nog niet bezig met het subscriben en uitvoeren van de data geplaatst door ProjectMaster (dit wordt een ander issue) maar gewoon een functionaliteit voor MQTT.

Op een raspberry pi zou dit gemakkelijk zijn met bijvoorbeeld Mosquitto broker. Op een microcontroller zal dit met veel opzoekingswerk zijn.

SampersS, 2023-10-09:
Dit is niet een broker configureren maar eigenlijk een subscriben via een python script

Closed 2023-10-09.

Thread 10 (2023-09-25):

Ledstrip kiezen

mSinnaeve04, 2023-09-25:
**Describe the Issue**
Kiezen welke ledstrip we gebruiken

**Additional context**

mSinnaeve04, 2023-09-25:
https://www.ledstripkoning.be/speciale-leds/dreamcolor-ws2811-led-strips/digitale-ws2812b-ledstrips/1-meter-ws2812b-digitale-rgb-ledstrip-premium-losse-strip

5V Ledstrip met Neo pixels

Closed 2023-09-25.

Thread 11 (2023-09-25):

Connectie meerdere modules

mSinnaeve04, 2023-09-25:
**Describe the Issue**
Hoe gaan we de verschillende tiles deftig verbinden?

**Additional context**

mSinnaeve04, 2023-10-02:
Datalijn doortrekken met connector en de 2de ledstrip terug verbinden met de voeding (Niet doorverbinden!!!)

Closed 2023-10-02.

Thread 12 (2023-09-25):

Raspberry Pi flashen

mSinnaeve04, 2023-09-25:
**Describe the Issue**
SD-kaart flashen voor de pi

**Additional context**
Add any other context about the problem here.

Closed 2023-09-25.

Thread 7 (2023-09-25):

Maak een prototype

SampersS, 2023-09-25:
**Describe the Issue**
Gewoon iets dat werkt waarmee we functies kunnen uit proberen

**Additional context**
Het mag uit elkaar vallen want het is maar een prototype

Closed 2023-10-09.

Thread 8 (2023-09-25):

Meeting, bespreking...

Rwill03, 2023-09-25:
**Describe the Issue**
A clear and concise description of what the issue is
Iedereen updaten met de huidige situatie
**Additional context**
Add any other context about the problem here.

Closed 2023-09-25.

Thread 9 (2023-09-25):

Geluidssensor kiezen

mSinnaeve04, 2023-09-25:
**Describe the Issue**
Kiezen welke geluidssensor

**Additional context**
/

mSinnaeve04, 2023-09-25:
https://www.otronic.nl/nl/geluidssensor-module-voor-arduino.html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

Closed 2023-09-25.

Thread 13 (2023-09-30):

Leren werken met wled

SampersS, 2023-09-30:
**Describe the Issue**
Het is belangrijk dat we weten wat wled is, hoe je het doet werken en hoe je het programmeert. Hiervoor moeten we zelf wat info zoeken op het internet zodat we snel kunnen starten volgende week maandag.

mSinnaeve04, 2023-10-02:
Geen wled gebruiken

Closed 2023-10-02.

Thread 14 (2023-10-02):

LEDs aansturen

mSinnaeve04, 2023-10-02:
**Describe the Issue**
LEDs zelf kunnen aansturen

**Additional context**
Add any other context about the problem here.

Closed 2023-10-09.

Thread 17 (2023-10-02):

LEDs testen

mSinnaeve04, 2023-10-02:
**Describe the Issue**
Testen als de leds werken

**Additional context**
Add any other context about the problem here.

mSinnaeve04, 2023-10-02:
De leds werken!

Closed 2023-10-02.

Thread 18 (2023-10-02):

Programma testen

mSinnaeve04, 2023-10-02:
**Describe the Issue**
Testen als de code werkt om de leds aan te sturen

**Additional context**
Add any other context about the problem here.

mSinnaeve04, 2023-10-02:
Het werkt

Closed 2023-10-02.

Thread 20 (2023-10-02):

Downloaden VNC Viewer software

estebandesmedt, 2023-10-02:
**Describe the Issue**
Installeren van de software voor het initialiseren en programmeren van de rasberry pi 4

**Additional context**
(https://www.realvnc.com/en/connect/download/viewer/)

Closed 2023-10-02.

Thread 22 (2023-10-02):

stand up meeting

PietKrobot, 2023-10-02:
**Describe the Issue**
stand up meeting voor het mechanisch ontwerp te bespreken

**Additional context**
Add any other context about the problem here.

Closed 2023-10-02.

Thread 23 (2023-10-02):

Git installeren op Pi

mSinnaeve04, 2023-10-02:
**Describe the Issue**
Git installeren zodat we op eigen pc kunnen programmeren en pushen vanop de pi

**Additional context**
Add any other context about the problem here.

Closed 2023-10-02.

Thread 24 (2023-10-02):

LED Effect maken

mSinnaeve04, 2023-10-02:
**Describe the Issue**
Proberen een effectje te maken met de LEDs

**Additional context**
Add any other context about the problem here.

Closed 2023-10-09.

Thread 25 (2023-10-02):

ReadMe template (tussentitels)

estebandesmedt, 2023-10-02:
**Describe the Issue**
<li>Introduction</li>
    <li>Project explained</li>
    <li>Hardware</li>
    <li>Software</li>
    <li>Who does what?</li>
    <li>Future changes</li>
    <li>Bill Of Materials</li>
    <li>Sources</li>
    <li>License and author info

**Additional context**
Add any other context about the problem here.

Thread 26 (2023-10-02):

SSH configuratie raspbarrypi

PietKrobot, 2023-10-02:
**Describe the Issue**
SSH configuratie raspberrypi maken voor het aazetten van VNC viewer

**Additional context**
Add any other context about the problem here.

Closed 2023-10-16.

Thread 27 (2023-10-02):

Searching way to supply power

estebandesmedt, 2023-10-02:
**Describe the Issue**
A clear and concise description of what the issue is

**Additional context**
Add any other context about the problem here.

Closed 2023-10-16.

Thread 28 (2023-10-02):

Brainstorm on how to connect cases as well as data/power

estebandesmedt, 2023-10-02:
**Describe the Issue**
A clear and concise description of what the issue is

**Additional context**
Add any other context about the problem here.

Closed 2023-10-16.

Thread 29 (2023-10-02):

Map voorbeeld code aanmaken

SampersS, 2023-10-02:
**Describe the Issue**
Er is een map nodig waar we de code snippets in zitten die we snel kunnen kopiëren voor onze code.

**Additional context**
Ook al die code op discord toevoegen.

Closed 2023-10-02.

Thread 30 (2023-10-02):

Random behavior

mSinnaeve04, 2023-10-02:
**Describe the bug**
Ledstrip doet gewoon random dingen

**To Reproduce**
Steps to reproduce the behavior:
1. run script4.py

**Expected behavior**
Rainbow

**Screenshots**
If applicable, add screenshots to help explain your problem.

**Additional context**
Add any other context about the problem here.

Closed 2023-10-09.

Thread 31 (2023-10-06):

Code zoeken

SampersS, 2023-10-06:
**Describe the Issue**
We moeten op zoek gaan naar nog meer code/scripts om de ledstrip aan te sturen die we dan kunnen uittesten maandag.

**Additional context**
Add any other context about the problem here.

Closed 2023-10-09.

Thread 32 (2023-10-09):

connectie leds

PietKrobot, 2023-10-09:
**Describe the Issue**
het sturen van de leds mogelijk maken

**Additional context**
Add any other context about the problem here.

Closed 2023-10-09.

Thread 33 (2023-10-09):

programma leds

PietKrobot, 2023-10-09:
**Describe the Issue**
het programma maken voor het sturen voor de leds

**Additional context**
Add any other context about the problem here.

Closed 2023-10-09.

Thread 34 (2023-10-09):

trouble shooting

PietKrobot, 2023-10-09:
**Describe the Issue**
trouble shooting voor het programmeren van de leds

**Additional context**
Add any other context about the problem here.

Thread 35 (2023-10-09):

trouble shooting led animatie

PietKrobot, 2023-10-09:
**Describe the Issue**
na het runnen van het programma kwamen de te bekomen en de effectieve effecten niet overeen

**Additional context**
Add any other context about the problem here.

Closed 2023-10-09.

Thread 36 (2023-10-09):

aanmaken programma

PietKrobot, 2023-10-09:
**Describe the Issue**
aanmaken programma voor de volledige led strip aan te sturen

**Additional context**
Add any other context about the problem here.

Closed 2023-10-09.

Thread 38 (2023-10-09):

Probleem LED strip oplossen (Helft komt achter bij rode kleur)

estebandesmedt, 2023-10-09:
**Describe the Issue**
A clear and concise description of what the issue is

**Additional context**
Add any other context about the problem here.

Closed 2023-10-09.

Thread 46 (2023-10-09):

Manier vinden om andere dozen te discoveren

SampersS, 2023-10-09:
het is belangrijk dat we het neopixel protocol hiervoor kennen

SampersS, 2023-10-16:
We kunnen dit niet doen door aantevragen hoeveel leds er zijn, er is geen manier voor dit op WS2812b.

SampersS, 2023-10-16:
we doen gewoon betere effectjes die niet caren om meerdere dozen of één doos.

Closed 2023-10-16.

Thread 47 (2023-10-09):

Kunnen subscriben op een topic van mqtt via een python script

SampersS, 2023-10-09:
**Describe the Issue**
Dit is voor project master

SampersS, 2023-10-09:
klaar, voorbeeld: Voorbeeld Code/mqttVoorbeeld.py
werkt op de raspberry pi confirmed, nu nog afwachten wat de broker van de project master is en welke functionaliteit we willen toegankelijk maken voor de project master.

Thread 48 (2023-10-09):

LED effecten programmeren

estebandesmedt, 2023-10-09:
**Describe the Issue**
A clear and concise description of what the issue is

**Additional context**
Add any other context about the problem here.

Closed 2023-10-09.

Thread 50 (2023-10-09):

Leds patroon maken

SampersS, 2023-10-09:
**Describe the Issue**
Dit was deze namidag en het is een regenboog

Closed 2023-10-09.

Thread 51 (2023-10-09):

mp3 bestanden inlezen met raspberry Pi

Rwill03, 2023-10-09:
**Describe the Issue**
A clear and concise description of what the issue is

**Additional context**
Add any other context about the problem here.

SampersS, 2023-10-15:
https://stackoverflow.com/questions/8635063/how-to-get-bpm-and-tempo-audio-features-in-python

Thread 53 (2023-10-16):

gpio pin uitlezen

SampersS, 2023-10-16:
**Describe the Issue**
Een programma dat in python de gpio pinnen kan uitlezen, voorbeeld voor later als we de microfoon willen binnen lezen

**Additional context**
sou sa nawimawemo hikari no mono ni wa

SampersS, 2023-10-16:
Voor digitaal uitlezen is dit al klaar maar
Voor analoog kan je niet uitlezen en heb je een adc converter nodig.

Closed 2023-10-16.

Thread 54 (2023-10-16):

GPIO pin uitlezen met geluidssensor

mSinnaeve04, 2023-10-16:
**Describe the Issue**
Data uit de geluidssensor krijgen via GPIO

**Additional context**
Add any other context about the problem here.

Closed 2023-10-16.

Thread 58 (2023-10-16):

Alles vastzetten in 3D-print

mSinnaeve04, 2023-10-16:
**Describe the Issue**
Hoe zorgen we dat alles vast zit in de behuizing?

**Additional context**
Add any other context about the problem here.

Closed 2023-10-16.

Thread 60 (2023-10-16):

Analoog uitlezen

SampersS, 2023-10-16:
**Describe the Issue**
Dit houd in dat we een adc maken voor een random voltage,
ik weet niet of we een 555-timer gaan nodig hebben maar ik ge eerst proberen erzonder

**Additional context**
nu is het python deel gewoon het gemakkelijkste.

SampersS, 2023-10-16:
beslist om dit niet analoog te doen, we moeten hiervoor een andere microfoon hebben

Closed 2023-10-16.

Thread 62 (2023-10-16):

voeden raspberry pi

PietKrobot, 2023-10-16:
**Describe the Issue**
Het uitproberen van de gekregen voeding en daarmee het voeden van de PI via de GPIO pins van de pi

**Additional context**
Add any other context about the problem here.

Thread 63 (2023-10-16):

Audio als input gebruiken voor LED

Rwill03, 2023-10-16:
**Describe the Issue**
A clear and concise description of what the issue is

**Additional context**
Add any other context about the problem here.

Closed 2023-11-13.

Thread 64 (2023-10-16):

LEDs aansturen zonder voeding

Rwill03, 2023-10-16:
**Describe the Issue**
A clear and concise description of what the issue is

**Additional context**
Add any other context about the problem here.

Closed 2023-10-16.

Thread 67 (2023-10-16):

lay-out leds

PietKrobot, 2023-10-16:
**Describe the Issue**
keuze lay out leds (leds = roze strepen)
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

**Additional context**
Add any other context about the problem here.

Closed 2023-10-16.

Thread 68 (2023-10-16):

micro

PietKrobot, 2023-10-16:
**Describe the Issue**
Keuze maken voor een micro die kan analoog binnen lezen op de pi via usb aangezien de pi geen analoge ingangen heeft in de GPIO dus hiervoor wordt USB gebruikt.
https://www.amazon.com.be/-/en/fasient-Microphone-Recording-Cancelling-Youtube/dp/B08BFHSLGV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

**Additional context**
Add any other context about the problem here.

Closed 2023-10-16.

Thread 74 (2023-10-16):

Raspberry Pi verder configureren

Rwill03, 2023-10-16:
**Describe the Issue**
A clear and concise description of what the issue is

**Additional context**
Add any other context about the problem here.

SampersS, 2023-10-16:
ondertussen al 3 nieuwe effectjes gemaakt

Closed 2023-10-16.

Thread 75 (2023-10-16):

Nieuwe  mic toevoegen aan bom

mSinnaeve04, 2023-10-16:
**Describe the Issue**
A clear and concise description of what the issue is

**Additional context**
Add any other context about the problem here.

Closed 2023-10-16.

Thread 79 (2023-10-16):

3D-prints in Excel

mSinnaeve04, 2023-10-16:
**Describe the Issue**
A clear and concise description of what the issue is

**Additional context**
Add any other context about the problem here.

Closed 2023-10-16.

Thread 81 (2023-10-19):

Aanvullen python libraries

SampersS, 2023-10-19:
**Describe the Issue**
Het is belangrijk wanneer we python code schrijven dat we dan kijken naar de libraries die we gebruiken en ze noteren in het bestand Python libraries in de root folder. We zouden in dit bestand dan een complete lijst moeten hebben van welke libraries we moeten installeren om onze code te doen werken.

**Additional context**
Laten we dit issue niet sluiten zodat we ons steeds zullen herinneren om deze good practice toe te passen.

Closed 2023-12-03.

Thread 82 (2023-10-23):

3D prints ontvangen

PietKrobot, 2023-10-23:
**Describe the Issue**
3D prints ontvangen

**Additional context**
Add any other context about the problem here.

Closed 2023-10-23.

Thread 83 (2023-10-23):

Microfoon integreren in Raspberry Pi

Rwill03, 2023-10-23:
**Describe the Issue**
A clear and concise description of what the issue is

**Additional context**
Add any other context about the problem here.

Closed 2023-10-23.

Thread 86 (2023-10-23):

Uitsnijden voorkant case, makers lab

estebandesmedt, 2023-10-23:
**Describe the Issue**
A clear and concise description of what the issue is

**Additional context**
Add any other context about the problem here.

Closed 2023-11-13.

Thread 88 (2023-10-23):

Geluid sensor

PietKrobot, 2023-10-23:
**Describe the Issue**
Instellen van de threshold van de sensor

**Additional context**
Add any other context about the problem here.

Closed 2023-11-06.

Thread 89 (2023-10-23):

een python script maken voor als er geluid is dan toont hij een random effect

SampersS, 2023-10-23:
**Describe the Issue**
A clear and concise description of what the issue is

**Additional context**
Add any other context about the problem here.

SampersS, 2023-11-06:
nu kan hij al alle leds aan doen met geluid, maar moet nog systeem verzinnen om effect af te spelen.
source code wordt zodadelijk upgeloadt.

mSinnaeve04, 2023-11-20:
Niet meer nodig

Closed 2023-11-20.

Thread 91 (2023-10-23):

Aanpassen van de mechanische tekeningen

PietKrobot, 2023-10-23:
**Describe the Issue**
Na het ontvangen van de 3D prints zijn er nog verschillende aanpassingen gebeurd aan de 3D tekeningen.

**Additional context**
Add any other context about the problem here.

Closed 2023-11-06.

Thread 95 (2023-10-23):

Library zoeken voor LED

Rwill03, 2023-10-23:
**Describe the Issue**
A clear and concise description of what the issue is

**Additional context**
Add any other context about the problem here.

Closed 2023-11-13.

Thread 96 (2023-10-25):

Checken voor error bij apparte files

SampersS, 2023-10-25:
**Describe the Issue**
Als we bij 1 python file de neopixellibrary gebruiken en bij een ander proberen een pin uit te lezen moeten we nagaan of het nogsteeds niet werkt als we ze bijden tergelijkertijd uitvoeren, zoniet dan kunnen we ons programma toch afmaken met imports en multithreadding.

**Additional context**
We kunnen dit zelf op een rpi testen zonder de opstelling, het enige wat we moeten doen in de ene file is gewoon de neopixellibrary importeren.

SampersS, 2023-11-06:
DIT WERKT!!!!!
bro we kunnen nu wel de digitale microfoon gebruiken.
lol

Closed 2023-11-06.

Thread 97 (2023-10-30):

Printen van deksel thuis

PietKrobot, 2023-10-30:
**Describe the Issue**
+-24H printen
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

**Additional context**
Add any other context about the problem here.

Closed 2023-10-30.

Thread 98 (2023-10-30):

verwijderen van support van nieuwe print

PietKrobot, 2023-10-30:
**Describe the Issue**
verwijderen van support van nieuwe print

**Additional context**
Add any other context about the problem here.

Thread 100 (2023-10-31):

lijmen support brackets leds

PietKrobot, 2023-10-31:
**Describe the Issue**
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

**Additional context**
Add any other context about the problem here.

Closed 2023-10-31.

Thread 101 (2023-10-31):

afknippen leds / solderen leds

PietKrobot, 2023-10-31:
**Describe the Issue**
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

**Additional context**
Add any other context about the problem here.

Closed 2023-10-31.

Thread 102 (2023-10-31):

Testen leds na solderen

PietKrobot, 2023-10-31:
**Describe the Issue**
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

**Additional context**
Add any other context about the problem here.

Closed 2023-10-31.

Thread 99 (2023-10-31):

3D printen nieuw deksel

PietKrobot, 2023-10-31:
**Describe the Issue**
printtijd 6,5uur
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

**Additional context**
Add any other context about the problem here.

Closed 2023-10-31.

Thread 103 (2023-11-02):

Leds opnieuw solderen

PietKrobot, 2023-11-02:
**Describe the Issue**
De leds zullen opnieuw gesoldeerd moeten worden met flexibelere draad die gemakkelijker weg te steken is in de behuizing.

**Additional context**
Add any other context about the problem here.

Closed 2023-11-06.

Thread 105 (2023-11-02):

prototype maken van de defuser types

PietKrobot, 2023-11-02:
**Describe the Issue**
Een simple (niet afgewerkt) prototype maken om de 2 verschillende types defuser te bepsreken en te vergelijken.
**Additional context**
Add any other context about the problem here.

Closed 2023-11-06.

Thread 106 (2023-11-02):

verschil tussen hoogte leds

PietKrobot, 2023-11-02:
**Describe the Issue**
er is een verschil in hoogte van de leds waarbij de ene leds die boven de raspberry pi komen dichter bij de defuser komen en dus meer licht naar buitenstralen. andere 2 leds misschien ook op brackets plaatsen om een gelijke lichtverhouding in de behuizing te krijgen.
**Additional context**
Add any other context about the problem here.

Closed 2023-11-20.

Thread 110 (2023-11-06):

Aanpassen behuizing voor reliëf in leafs

PietKrobot, 2023-11-06:
**Describe the Issue**
Dit als concept foto waarom we aanpassing doen aan behuizing

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

**Additional context**
Add any other context about the problem here.

Closed 2023-11-20.

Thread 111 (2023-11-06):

verwijderen supports voor leds boven pi

PietKrobot, 2023-11-06:
**Describe the Issue**
Het verwijderen van support voor de leds boven de pi om een even overzicht over de volledige behuizing te krijgen.

**Additional context**
Add any other context about the problem here.

Closed 2023-11-07.

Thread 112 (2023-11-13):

effect namen aanpassen

PietKrobot, 2023-11-13:
**Describe the Issue**
aanpassen van de effect namen naar een duidelijke vernaming en deze vervolgens beschrijven in de README

**Additional context**
Add any other context about the problem here.

Closed 2023-11-27.

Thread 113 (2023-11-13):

Code DRY maken

Rwill03, 2023-11-13:
**Describe the Issue**
De code DRY maken (Don't repeat yourself), zodat het leesbaarder is.

**Additional context**
Add any other context about the problem here.

Closed 2023-11-20.

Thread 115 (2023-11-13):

USB-Microphone integreren in de Raspberry Pi

Rwill03, 2023-11-13:
**Describe the Issue**
A clear and concise description of what the issue is

**Additional context**
Add any other context about the problem here.

Closed 2023-11-20.

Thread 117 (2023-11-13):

Weten hoe code uitvoeren bij opstart

SampersS, 2023-11-13:
**Describe the Issue**
Als we een apparaat willen dat werkt als je het in het stopcontact steekt dan moeten we weten hoe je code uitgevoerd krijgt als je het apparaat opstart, het is dus de bedoeling dat we dit opzoeken.

**Additional context**
nee

mSinnaeve04, 2023-11-15:
sudo nano /etc/rc.local
python3 /home/pi/myscript.py

SampersS, 2023-11-24:
getest met rc.local en werkend

Closed 2023-11-24.

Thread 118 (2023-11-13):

Connector aan LED solderen

estebandesmedt, 2023-11-13:
**Describe the Issue**
A clear and concise description of what the issue is

**Additional context**
Add any other context about the problem here.

Closed 2023-11-20.

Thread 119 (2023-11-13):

audiorecorder van meneer mees uitproberen

SampersS, 2023-11-13:
**Describe the Issue**
Ik kan het uitvoeren maar doet lijk niets

**Additional context**
Add any other context about the problem here.

SampersS, 2023-11-16:
dit is niet meer nodig sinds dat we de error die we hadden hebben opgelost.

Closed 2023-11-16.

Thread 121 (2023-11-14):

3D maken led behuizing dubbele hoogte

PietKrobot, 2023-11-14:
**Describe the Issue**
3D maken led behuizing dubbele hoogte

**Additional context**
Add any other context about the problem here.

Closed 2023-11-27.

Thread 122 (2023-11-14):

3D maken led behuizing

PietKrobot, 2023-11-14:
**Describe the Issue**
3D maken led behuizing

**Additional context**
Add any other context about the problem here.

Closed 2023-11-27.

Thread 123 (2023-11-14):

3D maken led deksel hub zonder pi

PietKrobot, 2023-11-14:
**Describe the Issue**
3D maken led deksel hub zonder pi

**Additional context**
Add any other context about the problem here.

Closed 2023-11-27.

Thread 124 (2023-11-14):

3D maken Led deksel hub

PietKrobot, 2023-11-14:
**Describe the Issue**
3D maken Led deksel hub

**Additional context**
Add any other context about the problem here.

Closed 2023-11-27.

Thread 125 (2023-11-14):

3D maken spacer dubbele hoogte behuizing zonder magneet

PietKrobot, 2023-11-14:
**Describe the Issue**
3D maken spacer dubbele hoogte behuizing zonder magneet

**Additional context**
Add any other context about the problem here.

Closed 2023-11-27.

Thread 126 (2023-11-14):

3D maken spacer dubbele hoogte behuizing

PietKrobot, 2023-11-14:
**Describe the Issue**
3D maken spacer dubbele hoogte behuizing

**Additional context**
Add any other context about the problem here.

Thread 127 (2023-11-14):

3D stl aanmaken

PietKrobot, 2023-11-14:
**Describe the Issue**
3D stl aanmaken 14-11-2023

**Additional context**
Add any other context about the problem here.

Closed 2023-11-27.

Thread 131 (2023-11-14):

3D readme aanmaken

PietKrobot, 2023-11-14:
**Describe the Issue**
om het duidelijk te maken wat en hoe alles moet geprint worden is er een readme voor de 3D prints aangemaakt

**Additional context**
Add any other context about the problem here.

Closed 2023-11-15.

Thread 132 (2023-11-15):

juiste parameters vinden voor geen overflow error

SampersS, 2023-11-15:
**Describe the Issue**
de error is als volgd:
Traceback (most recent call last):
  File "/home/elias/h.py", line 30, in <module>
    audio_data = np.frombuffer(stream.read(chunk_size), dtype=np.int16)
  File "/usr/lib/python3/dist-packages/pyaudio.py", line 608, in read
    return pa.read_stream(self._stream, num_frames, exception_on_overflow)
OSError: [Errno -9981] Input overflowed

**Additional context**
Add any other context about the problem here.

SampersS, 2023-11-15:
dit script is nu zelfredzaam

Closed 2023-11-15.

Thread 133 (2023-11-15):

script voor frequentie

SampersS, 2023-11-15:
**Describe the Issue**
het maken van een script om de frequentie te bepalen, dit is een issue die achter het feit werd aangemaakt om ons harde werkt op github issues te zetten zodat jullie niet denken dat we niet iets aan het doen zijn voor ons project. het script wordt nu opgeload naar github.

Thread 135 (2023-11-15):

script gemaak om decibels uit te lezen

SampersS, 2023-11-15:
**Describe the Issue**
nu de output op de leds zetten

**Additional context**
Add any other context about the problem here.

Closed 2023-11-15.

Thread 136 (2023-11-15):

extra effecten maken die reageren op geluid

SampersS, 2023-11-15:
**Describe the Issue**
Er zijn er al een paar maar deze zijn lijk niet zo mooi, voor inspiratie kijk naar:
[ledsMeDb.py](https://github.com/vives-project-xp/DancingLight/blob/main/Code/ledsMeDb.py)
[UitbreidReactie.py](https://github.com/vives-project-xp/DancingLight/blob/main/Code/UitbreidReactie.py)
[decibel.py](https://github.com/vives-project-xp/DancingLight/blob/main/Code/decibel.py)
[herdz.py](https://github.com/vives-project-xp/DancingLight/blob/main/Code/herdz.py)

Closed 2023-12-03.

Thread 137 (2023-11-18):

LedsMeDB.py ranges begrenzen met gemeten geluid

SampersS, 2023-11-18:
op dit moment zie je niet zo goed het reageren met geluid op LedsMeDB.py omdat het de sterkte van de leds bepaald op een schaal van max en minimum gemeten geluid, mijn bedoeling is om deze schaal aan te passen naar het minimuum van het recentelijk gemeten geluid en het maximuum.

SampersS, 2023-11-18:
gedaan + effect in decibel 1.1.py gezet

Closed 2023-11-18.

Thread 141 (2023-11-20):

schuren 3d print hoeken doos

estebandesmedt, 2023-11-20:
**Describe the Issue**
A clear and concise description of what the issue is

**Additional context**
Add any other context about the problem here.

Closed 2023-11-27.

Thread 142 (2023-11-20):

Solderen 2de ledstrip

mSinnaeve04, 2023-11-20:
**Describe the Issue**
Het 2de stuk ledstrip verknippen en solderen voor onze 2de doos

**Additional context**
Add any other context about the problem here.

Closed 2023-11-27.

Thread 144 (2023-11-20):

afdraaien stand offs magneten

PietKrobot, 2023-11-20:
**Describe the Issue**
afdraaien stand offs magneten

**Additional context**
Add any other context about the problem here.

Closed 2023-11-20.

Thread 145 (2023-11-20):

solderen tweede LED box

PietKrobot, 2023-11-20:
**Describe the Issue**
solderen tweede LED box

**Additional context**
Add any other context about the problem here.

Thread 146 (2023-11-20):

plaatsen van de standoffs in de 3 print

PietKrobot, 2023-11-20:
**Describe the Issue**
plaatsen van de standoffs in de 3 print

**Additional context**
Add any other context about the problem here.

Closed 2023-11-20.

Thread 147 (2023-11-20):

verwijderen support 3D prints

PietKrobot, 2023-11-20:
**Describe the Issue**
verwijderen support 3D prints

**Additional context**
Add any other context about the problem here.

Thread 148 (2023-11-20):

aansluitingen voor doorverbinden solderen

PietKrobot, 2023-11-20:
**Describe the Issue**
aansluitingen voor doorverbinden solderen

**Additional context**
Add any other context about the problem here.

Closed 2023-11-20.

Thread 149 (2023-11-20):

afschuren van 3D prints

PietKrobot, 2023-11-20:
**Describe the Issue**
afschuren van 3D prints

**Additional context**
Add any other context about the problem here.

Closed 2023-11-20.

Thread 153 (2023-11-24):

script maken die wacht waneer de microfoon klaar is

SampersS, 2023-11-24:
Een mogelijke oorzaak van de bug die we ervaren met als we een python script uitvoeren op startup is warschijnlijk dat de usb microfoon nog niet klaar is of geinitialiseerd is. dus we moeten een manier hebben om te weten te komen wanneer dat het klaar is en dan pas beginnen met de uitvoer van ons python script.

SampersS, 2023-11-24:
Dit blijkt niet het geval te zijn.

Closed 2023-11-24.

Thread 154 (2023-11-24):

script maken voor autoconfiguratie .asoundrc

SampersS, 2023-11-24:
Als je een audio input device wilt gebruiken voor de pi en gebruik maken van pyaudio dan moet je eerst .asoundrc configureren (hiermee dat het wel al gewerkt had), alleen verandert de instelling van met welke kaart het audioapparaat is aangesloten als we een script uitvoeren bij startup (ik weet het is random). Dus nu ga ik een script maken die dit bestand automatisch configureert bij en dan kunnen we dit script aanroepen voordat we verdergaan met de leds te doen dansen.

SampersS, 2023-11-24:
oke dit script is gemaakt maar werkt nog steeds niet (heeft 1 keer gewerkt maar is niet consistent). Ik wou dat de pi zich normaal zou gedragen.

Closed 2023-11-24.

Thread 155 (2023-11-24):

[Bevindingen] wat krijgen we bij welke kaart

SampersS, 2023-11-24:
Sound Card 2 & 3: Niets werkt
Sound Card 1: Werkt als je wat delay toevoegd in je functie bij opstart & alle code die handmatig gestart werd werkt.
Sound Card 0: Nog niet gezien vandaag

SampersS, 2023-11-24:
Alles is nu gefixt en werkt 100% van de keren bij bootup (steekproef van 3 keren)

Closed 2023-11-24.

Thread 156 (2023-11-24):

Kijken of het mogelijk is om een soundcard te forceren

SampersS, 2023-11-24:
de soundcard die hij gebruikt voor de usb microfoon is zo goed als random, maar we moeten kijken of we kunnen vooraf bepalen welke hij gebruikt. We zouden bij voorkeur Sound card 1 willen gebruiken sinds dat deze zonder problemen naar de alsa driver luistert.

SampersS, 2023-11-24:
oplossing 1: reboot tot dat soundcard1 gebruikt wordt.

SampersS, 2023-11-24:
alle namen van de kaarten (0 staat denkik altijd vast), de rest is altijd geshuffeld
0 - bcm2835 Headphones
1 - vc4-hdmi-0
2 - USB PnP Sound Device
3 - vc4-hdmi-1

SampersS, 2023-11-24:
belangrijk:
https://unix.stackexchange.com/questions/737309/how-to-gracefully-cope-with-alsa-card-moving-slots-across-reboot

SampersS, 2023-11-24:
door de volgende lijn toe te voegen aan /etc/modprobe.d/raspiblacklist.conf blijft de usb nummer 1
Helaas is dit niet genoeg, blijkbaar werkt kaart 1 nu ook niet meer.

SampersS, 2023-11-24:
oke nvm ik moest nog wat config files aanpassen die ik daarnet had aangepast voor te testen, maar nu werkt het welzeker.

Closed 2023-11-24.

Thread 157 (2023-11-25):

debuggen main.py

SampersS, 2023-11-25:
**Describe the Issue**
Kijken ofdat we de functies kunnen aanroepen aan de hand van mqtt, zoniet debuggen. Ook opzoek gaan naar de vermiste middenbounce functie en alleaudio reagerende functies toevoegen (ze zitten er nog niet in).

**Additional context**
Add any other context about the problem here.

SampersS, 2023-11-25:
debug gedaan en alle stuff van code erin gezet

Closed 2023-11-25.

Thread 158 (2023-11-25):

RGB uitlezen en implementeren

SampersS, 2023-11-25:
**Describe the Issue**
Verschillende effecten hebben een rgb variant of werken alleen maar met rgb, tot nu toe gebruikten we gewoon test waarden maar later zullen we ook de echte rgb-waarden moeten uitlezen.

**Additional context**
Er zijn ook functies die met geschaalde rgb werken (helderheid moet ook kunnen ingestelt worden) en de setbrightness functie werkt niet. dus normaal is rgb van 0 tot 255 maar wij zullen moeten werken met van 0 tot 7 (nog steeds veel kleuren mogelijk).

SampersS, 2023-11-27:
kan nu rgb en rgb2 (voor 2de doos) uitlezen en in code gebruiken

Closed 2023-11-27.

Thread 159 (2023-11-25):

mqtt parameters en effecten documenteren en doorgeven

SampersS, 2023-11-25:
**Describe the Issue**
We willen dat de mensen in projectmaster onze effecten weten, dus iemand moet ze allemaal eens bekijken en opschrijven (ook in de repo zetten) en dan doorgeven aan het project master team.

**Additional context**
Add any other context about the problem here.

SampersS, 2023-11-27:
is gedaan

Closed 2023-11-27.

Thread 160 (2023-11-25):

Opkuis pi + update scripts op github

SampersS, 2023-11-25:
**Describe the Issue**
Het is me opgevallen dat er veel nieuwe code op de pi aanwezeg is maar die niet op github staat, mogelijks ook wat debugcode die niet op github thuishoort. Ook staat de pi vol van bestanden die we vroeger hebben aangemaakt om dingen te testen (vooral in de home map) maar die we nu niet meer nodig hebben. Iemand moet deze opkuisen, of we kunnen ook gewoon de pi opnieuw flashen en kijken ofdat we met de gedocumenteerde setup de code aan de praat krijgen.

SampersS, 2023-11-27:
gebeurt, pi is nu weer fris

Closed 2023-11-27.

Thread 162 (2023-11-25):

mechanisme die door effecten loopt

SampersS, 2023-11-25:
Als je wilt mag je dit zelf een effect noemen, dit is eigenlijk bedoelt als standaard effect voor als de pi opstart, dan zal dit door alle effectjes loopen.

SampersS, 2023-11-27:
!!Update!!
Dit word gecanceld en het standaard effect die je krijgt als je hem opstart is ledsMeDb met Rgb (we moeten dit eerst maken)

SampersS, 2023-11-27:
oke werkt

Closed 2023-11-27.

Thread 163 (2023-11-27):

3D koppelstuk stl aanamken en toevoegen in 3D om te printen

PietKrobot, 2023-11-27:
**Describe the Issue**
3D koppelstuk stl aanamken en toevoegen in 3D om te printen

**Additional context**
Add any other context about the problem here.

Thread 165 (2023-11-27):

Stappenplan voor verse pi

SampersS, 2023-11-27:
Als we een nieuwe pi krijgen moeten we weten hoe we onze code uitvoerbaar krijgen.
Dit bevat:
-Libraries en software te installeren
-configuratie
-hoe uitvoeren op startup
-welke files moeten waar

mischien nog extra dingen, als het klaar is kunnen we eens proberen de pi te reseten en kijken of het werkt.

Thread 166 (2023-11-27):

Testen rgb kleuren raspberry

estebandesmedt, 2023-11-27:
**Describe the Issue**
A clear and concise description of what the issue is

**Additional context**
Add any other context about the problem here.

Closed 2023-11-27.

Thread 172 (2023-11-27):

opmeten input voltage

PietKrobot, 2023-11-27:
**Describe the Issue**
opmeten input voltage

**Additional context**
Add any other context about the problem here.

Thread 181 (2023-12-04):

Code maken voor voor elke doos een ander effect

SampersS, 2023-12-04:
via mqtt per doos een effect selecteren

SampersS, 2023-12-05:
Nu werkend, geconfigureerd voor 3 dozen maar kan makkelijk vermeerdert worden (code heel dynamisch), mischien moet nog iemand op zoek gaan naar bugs of een strestest voor de software maken. Ook Anycolor effect (oorspronkelijk effect voor 2 kleuren op de 2 dozen) en ledsMeDb verwijdert (ledsMeDb was omdat je door de waarden (255,255,255) door te geven aan ledsMeDbRGB het zelfde effect krijgt).

Closed 2023-12-05.

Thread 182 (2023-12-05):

Uitgebreide software stres-test

SampersS, 2023-12-05:
**Describe the Issue**
We hebben nu software die werkend is maar door heel complexe code met multithreading kunnen we niet direct alle bugs kennen, dus we moeten een test maken (kan ook mqtt gebruikend script zijn) en alle mogelijkheden uitproberen.

**Additional context**
Dit is een uitgebreid werkje die veel tijd in beslag zal nemen, we moeten dit enkel doen als we klaar zijn met de rest omdat de software nu werkt, alleen weten we niet of er nog bugs zijn. Ook is er de mogelijkheid dat ze in het 2de semester de code helemaal zullen moeten ombouwen voor nieuwe functionaliteiten/vereisten. Houd in je achterhooft dat dit nogsteed een proof of consept is op dit moment.

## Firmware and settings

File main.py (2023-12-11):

#packages importeren
import paho.mqtt.client as mqttClient
import time
import threading
import RPi.GPIO as GPIO
import board
import neopixel
import datetime
from math import log10
import math
import audioop
import pyaudio
import queue

#Als dit programma uitgevoerd wordt bij opstart dan is dit nodig omdat het anders start voor dat audio drivers en andere essentiele dingen opgestart zijn.
time.sleep(1)
doosNummer = [3]
#t1 = thread om effect op te laten uitvoeren, mainthread gaat controle uitvoeren over welk effect er in t1 zit.
doosThreads = [threading.Thread(),threading.Thread(),threading.Thread()]
muziekLuisteraars = [0]
#messages is een queue met het doorgegeven effecten via mqtt in, (queue voor bescherming tegen spam)
messages = queue.Queue()
#standaard effect starten
messages.put(("ledsMeDbRGB",1))
messages.put(("ledsMeDbRGB",2))

#in een array om er in andere threads ook aan te kunnen
#eerste is voor als het effect mag blijven runnen (wordt op false gezet door de mainthread), tweede is voor als het effect gestopt is dan weet de mainthread dat het een ander effect mag starten.
booleans = [[False, True],[False,True],[False,True]]#running, stoped
#mqtt rgb waarden uit de rgb topics komen hierin terecht en zijn altijd berijkbaar/aanpasbaar
rgb = [[255,255,0],[0,255,255],[255,0,255]]
#voor als we de command "off" krijgen, dan moeten we onthouden aan welk effect we zaten voor als het weer op "on" komt
laatsteEffect = ["ledsMeDbRGB","ledsMeDbRGB","ledsMeDbRGB"]
#configuratie binnenlezen
mqttfile = open("/mqttCred.conf","r")
configuratie = mqttfile.readlines()
#topics binnenlezen en in variabelen steken (laatste character is een \n dus je moet deze uitsluiten)
topicPath = configuratie[9][0:len(configuratie[9])-1]
effecttopic = configuratie[11][0:len(configuratie[11])-1]
rgbtopic = configuratie[13][0:len(configuratie[13])-1]
commandtopic = configuratie[15][0:len(configuratie[15])-1]

#functie die wordt uitgevoerd als we een bericht krijgen via mqtt
def on_message(client, userdata, message):
    #bericht decoderen
    bericht = str(message.payload.decode("utf-8"))
    topicIndex = -1
    for i in range(len(Topics)):
        if(Topics[i] == message.topic):
            topicIndex = i
            break
    if(topicIndex == -1): return
    #als het bericht van de effect topic afkomstig is.. de rest van de ifs begrijp je wel zelf
    if(topicIndex%3==0):
        #print("effect van topic:",message.topic,"heeft doosindex:", math.floor(topicIndex/3))
        #effect toevoegen aan de queue
        messages.put((bericht,math.floor(topicIndex/3)))
        #laatste effect updaten
        laatsteEffect[math.floor(topicIndex/3)] = bericht
    if(topicIndex%3==2):
        if(bericht == "ON"):
            messages.put((laatsteEffect[0],math.floor(topicIndex/3)))
        elif(bericht == "OFF"):
            messages.put(("off",math.floor(topicIndex/3)))
    if(topicIndex%3==1):
        dat = bericht.split(',')
        #als er foutieve data is dan worden de rgb waarden niet geupdate
        for i in range(3):
            try:
                rgb[math.floor(topicIndex/3)][i] = int(dat[i])%256 #om binnen 0-255 te blijven
            except:
                print("error data")
    print(message.topic,bericht)#snel bugs vinden

#functie wanneer de mqtt client verbinding maakt
def on_connect(client, userdata, flags, rc):
    if rc == 0:
  
        print("Connected to broker")
  
        global Connected                #Use global variable
        Connected = True                #Signal connection 
    else:
        print("Connection failed")

#root mean square berekenen
def callback(in_data, frame_count, time_info, status):
    global rms
    rms = audioop.rms(in_data, WIDTH) / 32767
    return in_data, pyaudio.paContinue

#Ledstrip instellingen definieren + pixel array (letterlijk een 1D array met de kleuren van alle leds) aanmaken
num_pixels = 96
pixel_pin = board.D18
ORDER = neopixel.GRBW
pixels = neopixel.NeoPixel(pixel_pin, num_pixels, auto_write=False, pixel_order=ORDER)

#audio componenten initialiseren
p = pyaudio.PyAudio()
WIDTH = 2
RATE = int(p.get_default_input_device_info()['defaultSampleRate'])
DEVICE = p.get_default_input_device_info()['index']
rms = 1
print(p.get_default_input_device_info())

#audio stream initialiseren maar nog niet starten
stream = p.open(format=p.get_format_from_width(WIDTH),
    input_device_index=DEVICE,
    channels=1,
    rate=RATE,
    input=True,
    output=False,
    stream_callback=callback)
#doe stream.start_stream() bij start van elke audio reactieve functie
#doe stream.stop_stream() bij het einde van elke audio reactieve functie
#doe stream.close() enkel maar op het einde (ander werkt het niet)

# Define colors
kleuren = [
    (255, 255, 255),    # White
    (0, 255, 0),        # Light Green
    (51, 204, 51),      # Green
    (51, 102, 0),       # Dark Green
    (51, 204, 255),     # Light Blue
    (0, 102, 255),      # Blue
    (0, 0, 204),        # Dark Blue
    (153, 102, 255),    # Light Purple
    (204, 0, 255),      # Purple
    (153, 0, 204),      # Dark Purple
    (255, 102, 255),    # Light Pink
    (255, 0, 255),      # Pink
    (153, 0, 153),      # Dark Pink
    (255, 80, 80),      # Light Red
    (255, 0, 0),        # Red
    (204, 0, 0),        # Dark Red
    (255, 153, 102),    # Light Orange
    (255, 102, 0),     # Orange
    (255, 255, 102),   # Light Yellow
    (255, 255, 0)      # Yellow
]
#pin voor de ledstrip data
Pin = 16
#nodig voor aansturen pin
GPIO.setup(Pin, GPIO.IN)

def fillPixelsIndex(r,g,b,doosIndex):
    for i in range((doosIndex*32),(doosIndex*32)+32):
        pixels[i] = (r,g,b)#rgb waarden van mqtt constant uitlezen
    pixels.show()

#hier zijn alle effecten aangepast om te werken met de threading:
#dit zijn effecten maar het is een beetje veel om bij ze allemaal een concrete werking te commenten, het is wel makkelijk te begrijpen
def rainbow(doosIndex):
    kleurindex = 0
    halvepixels = 0
    extra = 0
    while True:
        for i in range(halvepixels):
            pixels[16-halvepixels+i + (doosIndex*32)] = kleuren[(i+extra)%len(kleuren)]
            pixels[15+halvepixels-i+ (doosIndex*32)] = kleuren[(i+extra)%len(kleuren)]
        time.sleep(0.01)
        pixels.show()#dit commando zorgt ervoor dat alle kleuren aangewezen aan pixels worden weergegeven
        if(halvepixels == 16):
          extra += 1
        else:
          halvepixels += 1
        if(booleans[doosIndex][0] == False):   #als effect moet stoppen voor andere effecten
            break
    booleans[doosIndex][1] = True  #stopped op true zetten

    
def rgbKleur(doosIndex):
    while(True):
        for i in range(0+ (doosIndex*32),(doosIndex*32)+32):
            pixels[i] = (rgb[doosIndex][0], rgb[doosIndex][1], rgb[doosIndex][2])#rgb waarden van mqtt constant uitlezen
        pixels.show()
        time.sleep(1)
        if(booleans[doosIndex][0] == False):   #als effect moet stoppen voor andere effecten
            break
    booleans[doosIndex][1] = True  #stopped op true zetten


def ledsMeDbFlikker(doosIndex):
    minste = 0
    meeste = 1
    stream.start_stream()#voor te beginnen naar de microfoon te luisteren
    muziekLuisteraars[0] += 1
    recentmeeste = 0
    recentminste = 0
    nieuwcheckinterval = datetime.datetime.now() + datetime.timedelta(0,5)	#5 seconden vanaf n
    RGB = [0,0,0]
    iro_index = 0
    verhoogen = True
    while stream.is_active():
        db = 20 * log10(rms)#db gaat van -40 tot 0 somehow op dit apparaat
        positive = ((db+40))
        if(positive<minste):
            minste = positive
        if(positive>meeste):	#er is een bug waarbij positive 40 is bij eerste iteratie, ook is 40 de maximum waarde van het geluid toestel dus dit zullen we bijna nooit in de code als resultaat krijgen
            if positive == 40:
                positive = meeste
            meeste = positive
        if(positive<recentminste):
            recentminste = positive
        if(positive>recentmeeste):	#er is een bug waarbij positive 40 is bij eerste iteratie, ook is 40 de maximum waarde van het geluid toestel dus dit zullen we bijna nooit in de code als resultaat krijgen
            if positive == 40:
                positive = recentmeeste
            recentmeeste = positive
        if(datetime.datetime.now() > nieuwcheckinterval):
            meeste = recentmeeste
            minste = recentminste
            nieuwcheckinterval = datetime.datetime.now() + datetime.timedelta(0,5)
            recentminste = positive
            recentmeeste = positive
        filled_progbar  = round((positive-minste)/(meeste-minste)*16)
        if filled_progbar > 6:
            fillPixelsIndex(filled_progbar*RGB[0],filled_progbar*RGB[1],filled_progbar*RGB[2],doosIndex)
        else:
            fillPixelsIndex(0,0,0,doosIndex)
        if(verhoogen == True):
            RGB[iro_index%3] += 1
            if(RGB[iro_index%3] == 10):
                verhoogen = False
        else:
            RGB[iro_index%3] -= 1
            if(RGB[iro_index%3] == 0):
                verhoogen = True
                iro_index +=1
        if(booleans[doosIndex][0] == False):   #als effect moet stoppen voor andere effecten
            break
    muziekLuisteraars[0] -= 1
    booleans[doosIndex][1] = True  #stopped op true zetten
    
def ledsMeDbRGB(doosIndex):
    muziekLuisteraars[0] += 1
    stream.start_stream()
    minste = 0
    meeste = 1
    recentmeeste = 0
    recentminste = 0
    nieuwcheckinterval = datetime.datetime.now() + datetime.timedelta(0,5)
    while stream.is_active(): 
        db = 20 * log10(rms)#db gaat van -40 tot 0 somehow op dit apparaat
        positive = ((db+40))
        if(positive<minste):
            minste = positive
        if(positive>meeste):	#er is een bug waarbij positive 40 is bij eerste iteratie, ook is 40 de maximum waarde van het geluid toestel dus dit zullen we bijna nooit in de code als resultaat krijgen
            if positive == 40:
                positive = meeste
            meeste = positive
        if(positive<recentminste):
            recentminste = positive
        if(positive>recentmeeste):	#er is een bug waarbij positive 40 is bij eerste iteratie, ook is 40 de maximum waarde van het geluid toestel dus dit zullen we bijna nooit in de code als resultaat krijgen
            if positive == 40:
                positive = recentmeeste
            recentmeeste = positive
        if(datetime.datetime.now() > nieuwcheckinterval):
            meeste = recentmeeste
            minste = recentminste
            nieuwcheckinterval = datetime.datetime.now() + datetime.timedelta(0,5)
            recentminste = positive
            recentmeeste = positive
        filled_progbar  = ((positive-minste)/(meeste-minste))*16
        for i in range((doosIndex*32),(doosIndex*32)+32):
            pixels[i] = (((rgb[doosIndex][0]/16)*filled_progbar),round((rgb[doosIndex][1]/16)*filled_progbar),round((rgb[doosIndex][2]/16)*filled_progbar))#rgb waarden van mqtt constant uitlezen
        pixels.show()
        if(booleans[doosIndex][0] == False):   #als effect moet stoppen voor andere effecten
            break
    muziekLuisteraars[0] -= 1
    booleans[doosIndex][1] = True  #stopped op true zetten

def vlakMuziek(doosIndex):
    minste = 0
    meeste = 1
    recentmeeste = 0
    recentminste = 0
    nieuwcheckinterval = datetime.datetime.now() + datetime.timedelta(0,5)	#5 seconden vanaf nu
    index = 0
    verander = False
    stream.start_stream()
    muziekLuisteraars[0] += 1
    while stream.is_active(): 
        db = 20 * log10(rms)#db gaat van -40 tot 0 somehow op dit apparaat
        positive = ((db+40))
        if(positive<minste):
            minste = positive
        if(positive>meeste):	#er is een bug waarbij positive 40 is bij eerste iteratie, ook is 40 de maximwum waarde van het geluid toestel dus dit zullen we bijna nooit in de code als resultaat krijgen
            if positive == 40:
                positive = meeste
            meeste = positive
        if(positive<recentminste):
            recentminste = positive
        if(positive>recentmeeste):	#er is een bug waarbij positive 40 is bij eerste iteratie, ook is 40 de maximum waarde van het geluid toestel dus dit zullen we bijna nooit in de code als resultaat krijgen
            if positive == 40:
                positive = recentmeeste
            recentmeeste = positive
        if(datetime.datetime.now() > nieuwcheckinterval):
            meeste = recentmeeste
            minste = recentminste
            nieuwcheckinterval = datetime.datetime.now() + datetime.timedelta(0,5)
            recentminste = positive
            recentmeeste = positive
        filled_progbar  = round((positive-minste)/(meeste-minste))
        if filled_progbar> 0.5 and verander == False:
            verander = True
            index += 1
            fillPixelsIndex(kleuren[index%len(kleuren)][0],kleuren[index%len(kleuren)][1],kleuren[index%len(kleuren)][2],doosIndex)
        if(filled_progbar < 0.5):
            verander = False
        if(booleans[doosIndex][0] == False):   #als effect moet stoppen voor andere effecten
            break
    muziekLuisteraars[0] -= 1
    booleans[doosIndex][1] = True  #stopped op true zetten

def uitbreidReactie(doosIndex):
    stream.start_stream()
    muziekLuisteraars[0] += 1
    fillPixelsIndex(0,0,0,doosIndex)
    kleurlevels = [(20,20,20),(50,20,20),(140,20,20),(255,20,20),(20,50,20),(20,140,20),(20,255,20),(20,20,50),(20,20,140),(20,20,255)]#10 levels in totaal
    stream.start_stream()
    while stream.is_active(): 
        db = 20 * log10(rms)#db gaat van -40 tot 0 somehow op dit apparaat
        geluidIndexMidden = round(((db+40)/10)%1*11)-1#van -1 tot 10
        for j in range(3):
            color = (0,0,0)
            if geluidIndexMidden-j >= 0 and geluidIndexMidden-j < 10:
                color = kleurlevels[geluidIndexMidden-j]
            for i in range(4):
                pixels[i*8+3-j+32*doosIndex] = color
                pixels[i*8+4+j+32*doosIndex] = color
        pixels.show()
        if(booleans[doosIndex][0] == False):   #als effect moet stoppen voor andere effecten
            break
    muziekLuisteraars[0] -= 1
    booleans[doosIndex][1] = True  #stopped op true zetten
    
def MiddenBounce(doosIndex):
    kleurindex = 0
    aantal = 16
    index = 0
    while True:
        kleur = kleuren[index]
        for i in range(aantal):
            pixel = 32*doosIndex
            furtherpixel = 32*(doosIndex+1)-1
            pixels[pixel+i] = kleur
            pixels[furtherpixel-i] = kleur
            pixels.show()
        for i in range(aantal):
            pixel = 32*doosIndex
            furtherpixel = 32*(doosIndex+1)-1
            pixels[pixel+aantal-i] = (0,0,0)
            pixels[furtherpixel-aantal+i] = (0,0,0)
            pixels.show()
        index += 1
        if index == len(kleuren):
            index = 0
        fillPixelsIndex(0,0,0,doosIndex)
        if(booleans[doosIndex][0] == False):   #als effect moet stoppen voor andere effecten
            break
    booleans[doosIndex][1] = True  #stopped op true zetten

Connected = False   #global variable for the state of the connection
#deze code wordt nog steeds enkel in het begin uitgevoert, hiervoor waren het 
#mqtt instellingen configureren
broker_address= configuratie[3][0:len(configuratie[3])-1] #"projectmaster.devbit.be"  #Broker address
port =int(configuratie[1])               #Broker port
print(port)
user = configuratie[5][0:len(configuratie[5])-1]#plaats dit in de repo zonder wachtwoorden
password = configuratie[7][0:len(configuratie[7])-1]#Connection password
  
#paho mqtt client aanzetten
client = mqttClient.Client("raspberry pi")               #create new instance
client.username_pw_set(user, password=password)    #set username and password
client.on_connect= on_connect                      #attach function to callback
client.on_message= on_message                      #attach function to callback
client.connect(broker_address, port=port)          #connect to broker
client.loop_start()        #start the loop

#wacht tot er verbinding is met de mqtt broker
while Connected != True:
    time.sleep(0.1)

#subscriben op alle topics die in het config bestand stonden
sublist = []
Topics = []
for i in range(doosNummer[0]):
    Topics.append(topicPath+str(i)+effecttopic)
    Topics.append(topicPath+str(i)+rgbtopic)
    Topics.append(topicPath+str(i)+commandtopic)
    for j in range(3):
        sublist.append((Topics[i*3+j],0))
client.subscribe(sublist)
print(Topics)

try:
    #oneindige lus starten in de main thread
    while True:
        #wordt elke seconde uitgevoerd (als hij niet ergens blijft hangen)(1 seconde + loop tijd)
        time.sleep(1)
        #als er een bericht binnen kwam (effect)
        if (messages.qsize()>0):
            short = messages.get()
            bericht = short[0]
            Topicindex = short[1]
            print("Message received:",bericht,"voor doos:", Topicindex)#voor debug
            booleans[Topicindex][0] = False #sein geven aan effect thread om op te houden
            if booleans[Topicindex][1] == False:
                while booleans[Topicindex][1]==False:
                    time.sleep(0.1)
                    print("wait", booleans[Topicindex][1])#zolang dat de thread nog niet gestopt is
                doosThreads[Topicindex].join()#alleen joinen als hij al aan het runnen was (dus niet voor het eerste effect)
            if(muziekLuisteraars[0] == 0):
                stream.stop_stream()
            if bericht == "rainbow":#als bericht == effect naam: t1 = thread(effect), altijd hetzelfde
                doosThreads[Topicindex] = threading.Thread(target=rainbow, kwargs={"doosIndex":Topicindex})
                booleans[Topicindex][0] = True
                booleans[Topicindex][1] = False
                doosThreads[Topicindex].start()
            if bericht == "rgbKleur":
                doosThreads[Topicindex] = threading.Thread(target=rgbKleur, kwargs={"doosIndex":Topicindex})
                booleans[Topicindex][0] = True
                booleans[Topicindex][1] = False
                doosThreads[Topicindex].start()
            if bericht == "off":
                fillPixelsIndex(0,0,0,Topicindex)
            if bericht == "ledsMeDbFlikker":
                doosThreads[Topicindex] = threading.Thread(target=ledsMeDbFlikker, kwargs={"doosIndex":Topicindex})
                booleans[Topicindex][0] = True
                booleans[Topicindex][1] = False
                doosThreads[Topicindex].start()
            if bericht == "ledsMeDbRGB":
                doosThreads[Topicindex] = threading.Thread(target=ledsMeDbRGB, kwargs={"doosIndex":Topicindex})
                booleans[Topicindex][0] = True
                booleans[Topicindex][1] = False
                doosThreads[Topicindex].start()
            if bericht == "vlakMuziek":
                doosThreads[Topicindex] = threading.Thread(target=vlakMuziek, kwargs={"doosIndex":Topicindex})
                booleans[Topicindex][0] = True
                booleans[Topicindex][1] = False
                doosThreads[Topicindex].start()
            if bericht == "uitbreidReactie":
                doosThreads[Topicindex] = threading.Thread(target=uitbreidReactie, kwargs={"doosIndex":Topicindex})
                booleans[Topicindex][0] = True
                booleans[Topicindex][1] = False
                doosThreads[Topicindex].start()
            if bericht == "MiddenBounce":
                doosThreads[Topicindex] = threading.Thread(target=MiddenBounce, kwargs={"doosIndex":Topicindex})
                booleans[Topicindex][0] = True
                booleans[Topicindex][1] = False
                doosThreads[Topicindex].start()
#dingen afhandelen als ctrl+c wordt ingedrukt
except KeyboardInterrupt:
    tel = 0
    for threa in doosThreads:
        booleans[tel][0] = False
        if booleans[tel][1] == False:
            while booleans[tel][1]==False:
                time.sleep(0.1)
            threa.join()
        tel+=1
    print("exiting")
    client.disconnect()
    client.loop_stop()
    GPIO.cleanup()
    stream.close()
    p.terminate()

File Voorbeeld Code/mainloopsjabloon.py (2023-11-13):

import paho.mqtt.client as mqttClient
import time
import threading
import RPi.GPIO as GPIO
import board
import neopixel

t1 = threading.Thread()
messages = []
booleans = [False, True]#running, stoped

def rainbow():
    while(True):
        pixels.fill(colors[1])
        pixels.show()
        time.sleep(1)
        pixels.fill(colors[2])
        pixels.show()
        time.sleep(1)
        print(booleans[0])
        if booleans[0] == False:
            booleans[1]=True
            break
def allLights():
    pixels.fill(colors[6])
    pixels.show()
    booleans[1] = True

def on_message(client, userdata, message):
    bericht = str(message.payload.decode("utf-8"))
    messages.append(bericht)
    print(messages)

def on_connect(client, userdata, flags, rc):
  
    if rc == 0:
  
        print("Connected to broker")
  
        global Connected                #Use global variable
        Connected = True                #Signal connection 
  
    else:
  
        print("Connection failed")
  
# Configure the Neopixel ring
num_pixels = 64
pixel_pin = board.D18
ORDER = neopixel.GRBW

pixels = neopixel.NeoPixel(pixel_pin, num_pixels, auto_write=False, pixel_order=ORDER)

# Define colors
colors = [
    (255, 255, 255),    # White
    (0, 255, 0),        # Light Green
    (51, 204, 51),      # Green
    (51, 102, 0),       # Dark Green
    (51, 204, 255),     # Light Blue
    (0, 102, 255),      # Blue
    (0, 0, 204),        # Dark Blue
    (153, 102, 255),    # Light Purple
    (204, 0, 255),      # Purple
    (153, 0, 204),      # Dark Purple
    (255, 102, 255),    # Light Pink
    (255, 0, 255),      # Pink
    (153, 0, 153),      # Dark Pink
    (255, 80, 80),      # Light Red
    (255, 0, 0),        # Red
    (204, 0, 0),        # Dark Red
    (255, 153, 102),    # Light Orange
    (255, 102, 0),     # Orange
    (255, 255, 102),   # Light Yellow
    (255, 255, 0)      # Yellow
]
Pin = 16

GPIO.setup(Pin, GPIO.IN)


Connected = False   #global variable for the state of the connection
  
broker_address= "test.mosquitto.org" #"projectmaster.devbit.be"  #Broker address
port = 1883               #Broker port
user = ""#"Elias"            #plaats dit in de repo zonder wachtwoorden
password = ""#"Elias"            #Connection password
  
client = mqttClient.Client("phillips")               #create new instance
client.username_pw_set(user, password=password)    #set username and password
client.on_connect= on_connect                      #attach function to callback
client.on_message= on_message                      #attach function to callback
  
client.connect(broker_address, port=port)          #connect to broker
  
client.loop_start()        #start the loop
  
while Connected != True:    #Wait for connection
    time.sleep(0.1)
  
client.subscribe("sigma")
  
try:
    while True:
        time.sleep(1)
        print("lengte list " + str(len(messages)))
        if(len(messages)>0):
            bericht = messages.pop()
            print("Message received: "  + bericht+ "; booleans[1]=",booleans[1])
            booleans[0] = False
            if booleans[1] == False:
                while booleans[1]==False:
                    time.sleep(0.1)
                    print("wait", booleans[1])
                t1.join()
            if bericht == "rainbow":
                t1 = threading.Thread(target=rainbow)
                booleans[0] = True
                booleans[1] = False
                t1.start()
            if bericht == "off":
                t1 = threading.Thread(target=allLights)
                booleans[0] = True
                booleans[1] = False
                t1.start()
  
except KeyboardInterrupt:
    booleans[0] = False
    print("exiting")
    client.disconnect()
    client.loop_stop()

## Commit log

2023-10-02 Toevoeg code van github
    de glimlach van superidol is niet zo stralend als jij.
2023-10-02 Script 4 terug gehaald
    スクリプト4を取り戻せ
2023-10-09 mqtt subscribe voorbeeldcode upload
    we kunnen dit hopelijk ook gebruiken op de pi
2023-10-16 Create gpiopinpinpinpin.py
    voor digitaal uitlezen pin
2023-10-16 3D_tekeningen toevoegen
    [Koppelstuk.stl, Led behuizing main unit.stl, Led deksel main unit.stl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]
2023-10-23 Create threadink.py
    soda
2023-11-12 led detection
2023-11-13 cut picture
2023-11-15 Create UitbreidReactie.py
    nog extra effect die op geluid reageerd
2023-11-18 Create vlakMuziek.py
    dit is een effect die van kleur verandert als de decibels omhoog gaan, werkt goed met muziek die een duidelijke beat heeft maar niet met klasieke muziek.
2023-11-25 Update main.py
    Alle stuff is nu toegevoegd aan main.py
    geen bugs gevonden maar ook nog niet zwaar getest.
    [main.py]
2023-11-27 bom change
2023-12-02 ledsMeRGB nu van 0-16 naar 0-255
    later afronden.
2023-12-04 Update main.py
    py ass bugs verwijdert
    [main.py]
2023-12-04 commentaar main.py
    nu kunnen noobs de structuur en acties in dit programma begrijpen
2023-12-07 Removed 2 files bc README
    [alsa configuratie.txt]
